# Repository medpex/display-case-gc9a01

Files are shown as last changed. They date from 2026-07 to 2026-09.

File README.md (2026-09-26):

# Display-Case GC9A01 — Tilted Desk Stand

A 15°-tilted desk stand for a round **GC9A01 1.28" TFT** (240×240, SPI) with an
integrated **ESP32-C3 Super Mini**. USB-C reachable from the outside. Print-ready
for Bambu Lab (0.4 mm nozzle, PLA, no supports).

> **Firmware without a toolchain:** flash the display right from your browser —
> **[open the Web Flasher »](https://medpex.github.io/display-case-gc9a01/)**
> (Chrome or Edge, desktop).

**📦 Download the model on [MakerWorld](https://makerworld.com/de/models/3082754-tischstander-fur-gc9a01-1-28-display-esp32-c3).**

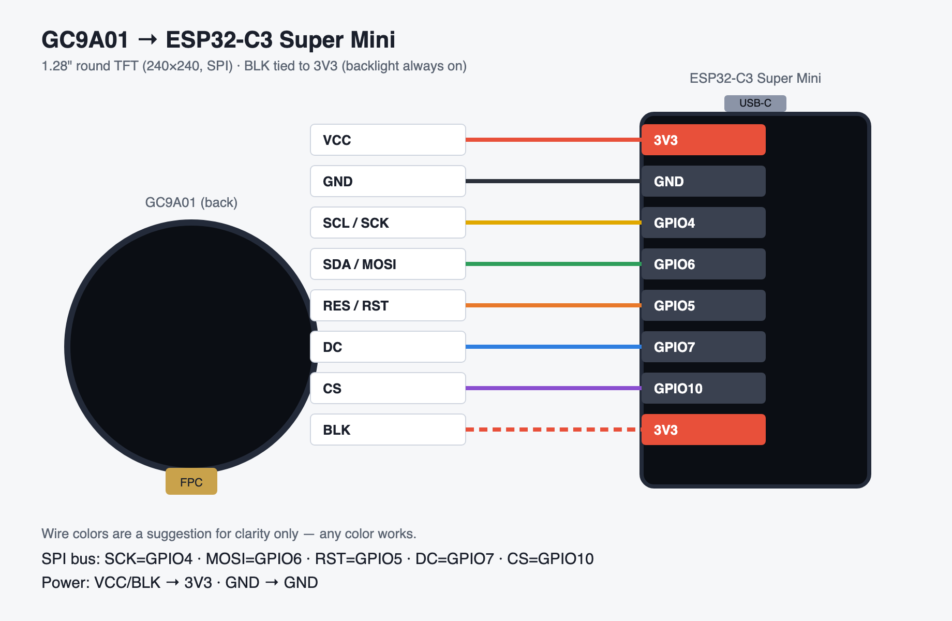
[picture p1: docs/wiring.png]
Wiring diagram


## Housing variants

Both housings use the same electronics, wiring and firmware (web flasher above).

| | Variant | Folder |
|---|---|---|
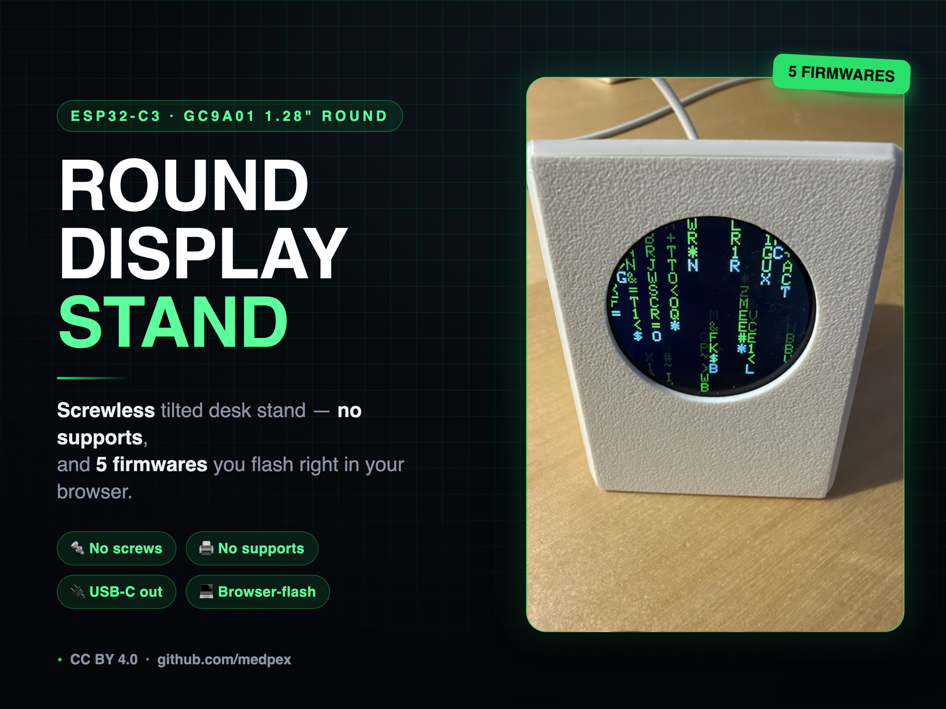
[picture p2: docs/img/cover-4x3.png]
|  | **Wedge stand** (original): 15° wedge, 58 × 52 × 66 mm | this folder (`STL/`, `3MF/`, `STEP/`) |
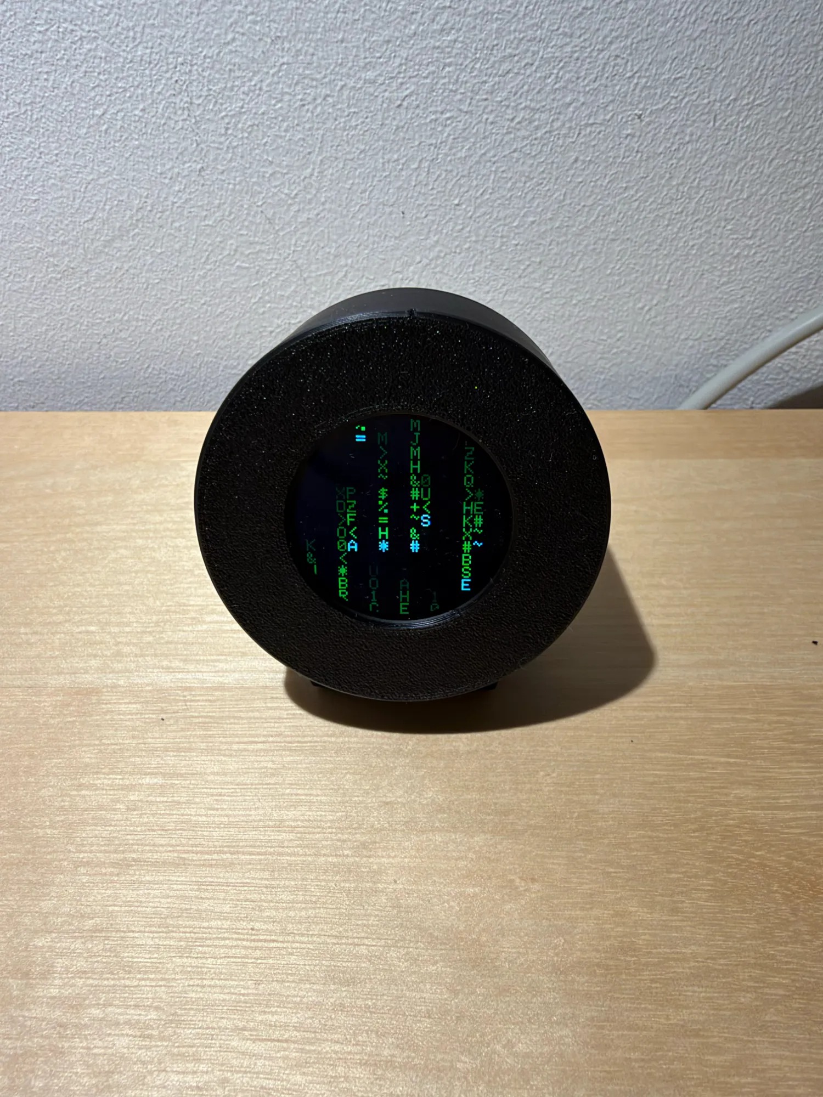
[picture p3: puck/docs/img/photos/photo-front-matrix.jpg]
|  | **Round puck**: ⌀64 mm puck, 15° tilt, wedge foot, lid with ESP32 snap sled | [`puck/`](puck/README.md) |

## Contents

```
Display-Case-GC9A01/
├── STL/                          # print-ready meshes
│   ├── FINAL-Case.stl
│   ├── FINAL-Deckel.stl          # lid (snap-fit)
│   └── FINAL-Klemmring.stl       # clamp ring (holds the display)
├── 3MF/CASE-FINAL-alle-teile.3mf # all parts in one file
├── STEP/CASE-FINAL.step          # parametric CAD (Fusion import)
├── Firmware/
│   ├── esp32_hud/                # GC9A01 HUD (clock/weather/sun/date, WiFi portal)
│   ├── esp32_starfield/          # Warp starfield demo (no WiFi)
│   ├── esp32_matrix/             # Matrix rain demo (no WiFi)
│   ├── esp32_fire/               # demoscene fire demo (no WiFi)
│   └── esp32_plasma/             # full-color plasma demo (no WiFi)
├── puck/                         # round puck variant (own STL/3MF/STEP, Fusion source)
├── docs/                         # GitHub Pages web flasher + wiring diagram
└── BOM.md                        # bill of materials
```

## Wiring (GC9A01 → ESP32-C3 Super Mini)

| Display | ESP32-C3 GPIO |
|---|---|
| VCC | 3V3 |
| GND | GND |
| SCL / SCK | GPIO4 |
| SDA / MOSI | GPIO6 |
| RES / RST | GPIO5 |
| DC | GPIO7 |
| CS | GPIO10 |
| BLK | 3V3 (backlight always on) |

## Firmware

Two sketches are included. Two ways to flash:

### 1. Web flasher (easiest — no software)

Open **<https://medpex.github.io/display-case-gc9a01/>** in Chrome or Edge on a
desktop, plug the ESP32-C3 in via USB-C, and click a flash button. That's it.

- **GC9A01 HUD** — rotating info display: clock, weather, daylight/sun arc and date,
  with a short random animation show once per hour. WiFi and location are set up in
  the browser on first boot (see below). No cloud, no account, no telemetry.
- **Demos** (no WiFi, no setup, run instantly):
  - **Warp Starfield** — flicker-free warp-speed flight through the stars
  - **Matrix Rain** — falling glyph columns with fading trails
  - **Fire** — old-school demoscene fire simulation
  - **Plasma** — full-color plasma waves cycling through the rainbow

#### HUD first-time setup

On first boot the HUD opens a WiFi hotspot **`GC9A01-HUD-Setup`**. Connect a
phone/laptop to it; a captive portal appears where you:

1. select your home WiFi and enter the password;
2. optionally set **City** (display label), **Latitude**, **Longitude** and
   **Timezone** (POSIX, e.g. `CET-1CEST,M3.5.0,M10.5.0/3`) for weather and the clock.

Settings are saved on the device (NVS). Time comes from NTP, weather from
[Open-Meteo](https://open-meteo.com) (no API key). Defaults to Berlin if you skip the
location fields. To change WiFi/location later, flash again — an erase re-opens the portal.

### 2. Self-compile (arduino-cli)

Requires the `esp32:esp32` core ≥ 3.3.7. Important: **`CDCOnBoot=cdc`** (otherwise no
serial / auto-upload on the C3 Super Mini).

```bash
# HUD — libs: "GFX Library for Arduino", ArduinoJson, WiFiManager (tzapu)
arduino-cli compile --upload -p /dev/cu.usbmodemXXXX \
  --fqbn "esp32:esp32:esp32c3:CDCOnBoot=cdc,FlashSize=4M,PartitionScheme=huge_app" \
  Firmware/esp32_hud

# Demos (starfield / matrix / fire / plasma) — libs: "Adafruit GFX Library", "Adafruit GC9A01A"
arduino-cli compile --upload -p /dev/cu.usbmodemXXXX \
  --fqbn "esp32:esp32:esp32c3:CDCOnBoot=cdc,FlashSize=4M" \
  Firmware/esp32_starfield   # or esp32_matrix / esp32_fire / esp32_plasma
```

> Default location can also be changed in `Firmware/esp32_hud/esp32_hud.ino`
> (`DEF_CITY` / `DEF_LAT` / `DEF_LON` / `DEF_TZ`) before compiling.

## Print settings

- **Material:** PLA
- **Layer height:** 0.2 mm
- **Walls:** 1.7 mm (= 4 perimeters at 0.4 mm nozzle)
- **Infill:** ~15 % gyroid
- **Supports:** none (only a short bridge over the USB-C port, prints free)
- **Orientation:** case lying on its back/bottom; lid & clamp ring flat.

## Assembly

1. Drop the display into the boss from the front (D-shape/chin down, FPC through the notch).
2. Put the **clamp ring** on from the back — fixes the display; align its opening to the FPC.
3. Click the ESP32-C3 into the snap holder in the lower area, USB-C toward the port.
4. Wire it up per the table above.
5. Click the **lid** in (snap-fit) — bottom closes flush.
6. Optionally stick 4× rubber feet under the base.

## CAD notes

- Import `STEP/CASE-FINAL.step` into an empty Fusion document to keep editing.
- Internal Fusion length unit = cm; model authored in mm (`c(x)=x*0.1`).
- Key dimensions: wedge 58 D × 52 W × 66 H mm, wall 1.7, floor 2.0, tilt 15°.

## License

- **[Standard Digital File License](LICENSE)** (matches the MakerWorld listing) —
  personal, non-commercial use only. No sharing, remixing, redistribution, hosting
  or commercial use without permission.
- Attribution: *Display-Case GC9A01 by medpex*.
```

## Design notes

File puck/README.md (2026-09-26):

# Display-Puck GC9A01 — Round 15° Desk Puck

A round, 15°-tilted desk puck for a **GC9A01 1.28" round TFT** (240×240, SPI) with an
integrated **ESP32-C3 Super Mini**. It is a variant of
[Display-Case GC9A01](https://makerworld.com/de/models/3082754-tischstander-fur-gc9a01-1-28-display-esp32-c3)
and uses the same electronics, wiring and firmware, in a puck-shaped housing with an
integrated wedge foot. USB-C comes out the back. No screws, no supports.

This folder is part of the [display-case-gc9a01](../README.md) repo. Firmware, web flasher
and wiring diagram live in the repo root.

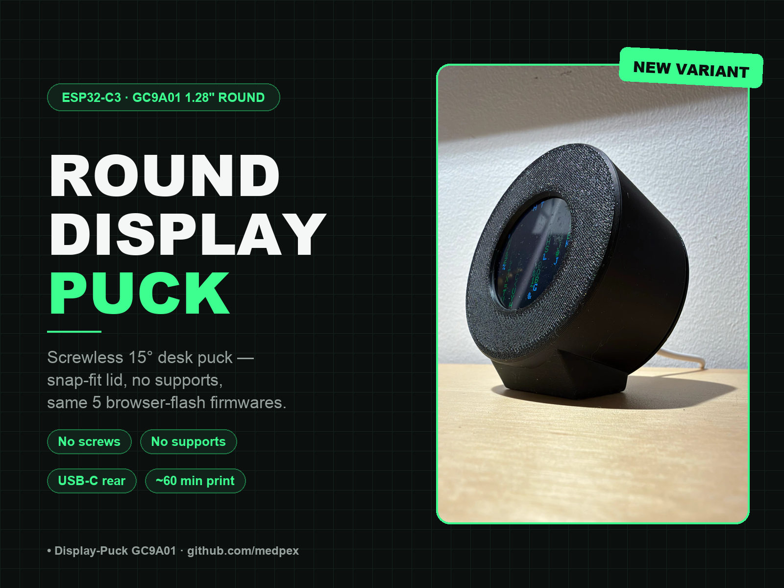
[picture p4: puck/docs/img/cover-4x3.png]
Cover


| Front | Angle | Inside (lid v2 with ESP32 sled) |
|---|---|---|
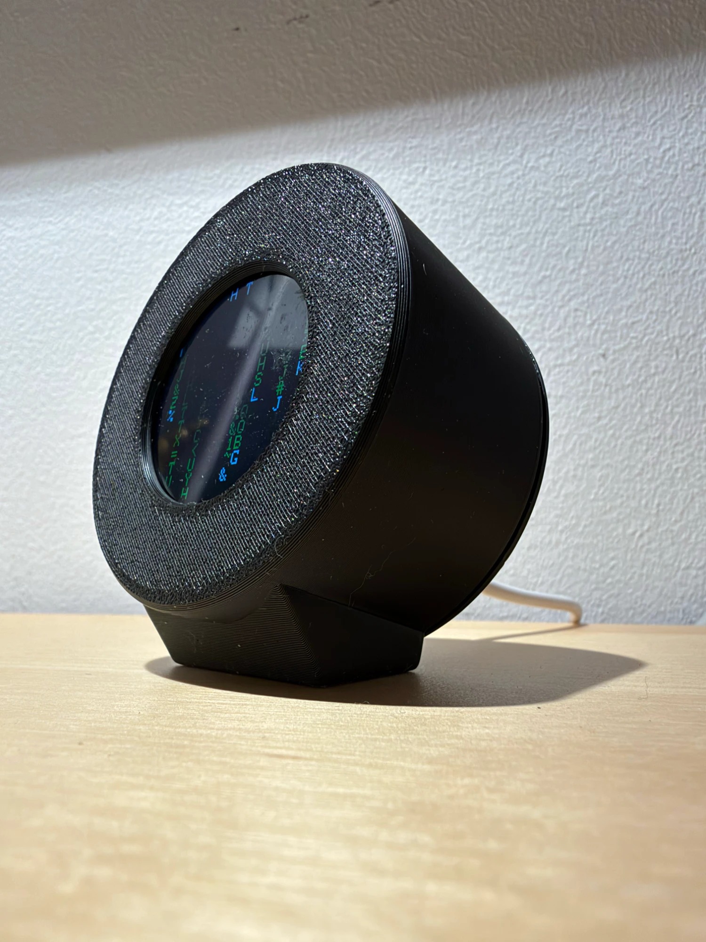
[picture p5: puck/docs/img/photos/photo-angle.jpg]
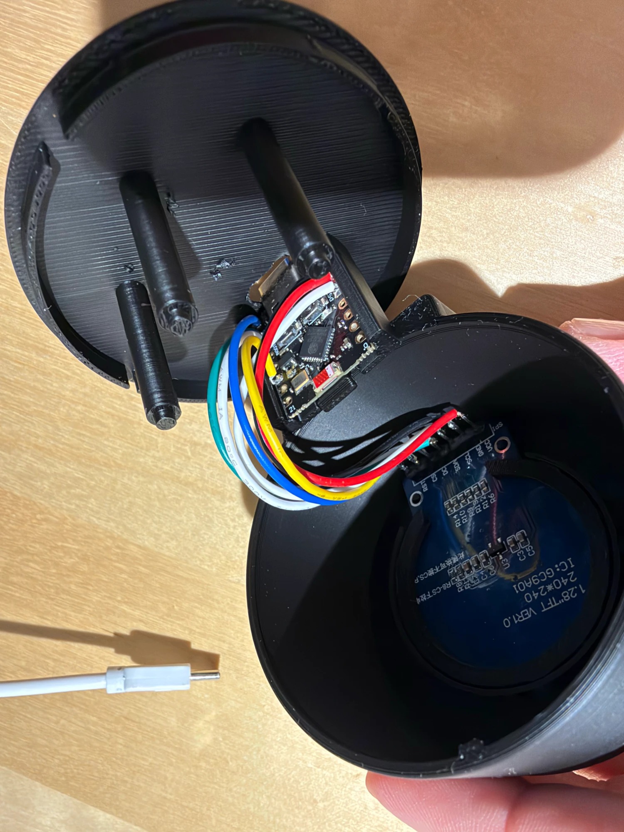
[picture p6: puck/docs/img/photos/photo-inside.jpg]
|  |  |  |

> **Firmware:** same as the original — flash it from your browser with the
> **[Web Flasher](https://medpex.github.io/display-case-gc9a01/)** (Chrome/Edge, desktop).
> The display sits in the same orientation (chin down), so every firmware works unchanged.

| Render | Exploded | Lid v2 with ESP32-C3 |
|---|---|---|
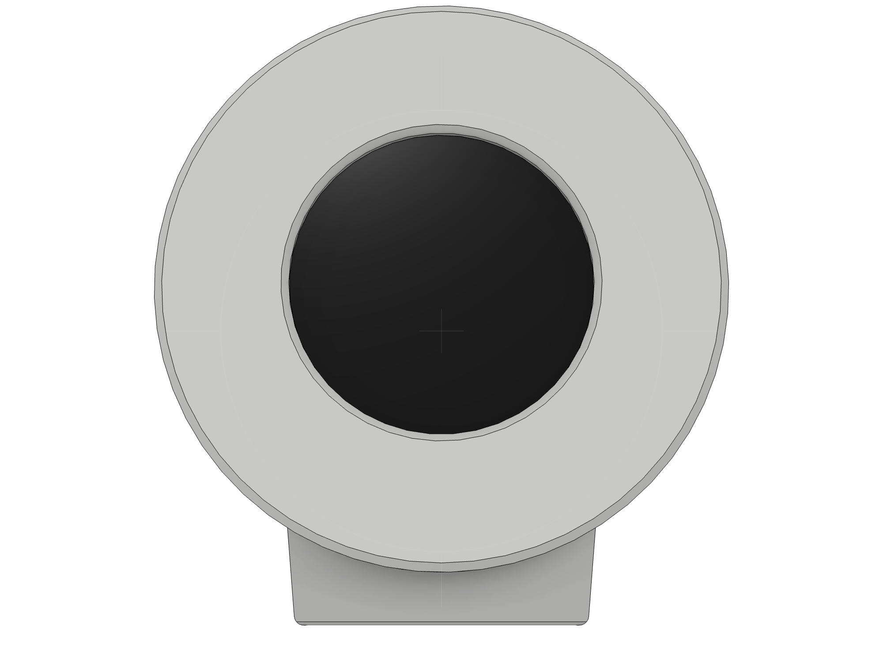
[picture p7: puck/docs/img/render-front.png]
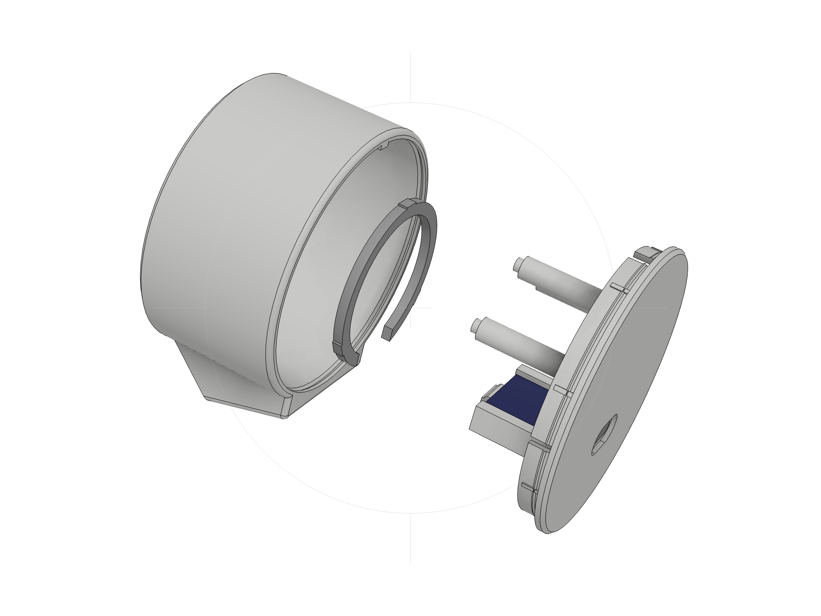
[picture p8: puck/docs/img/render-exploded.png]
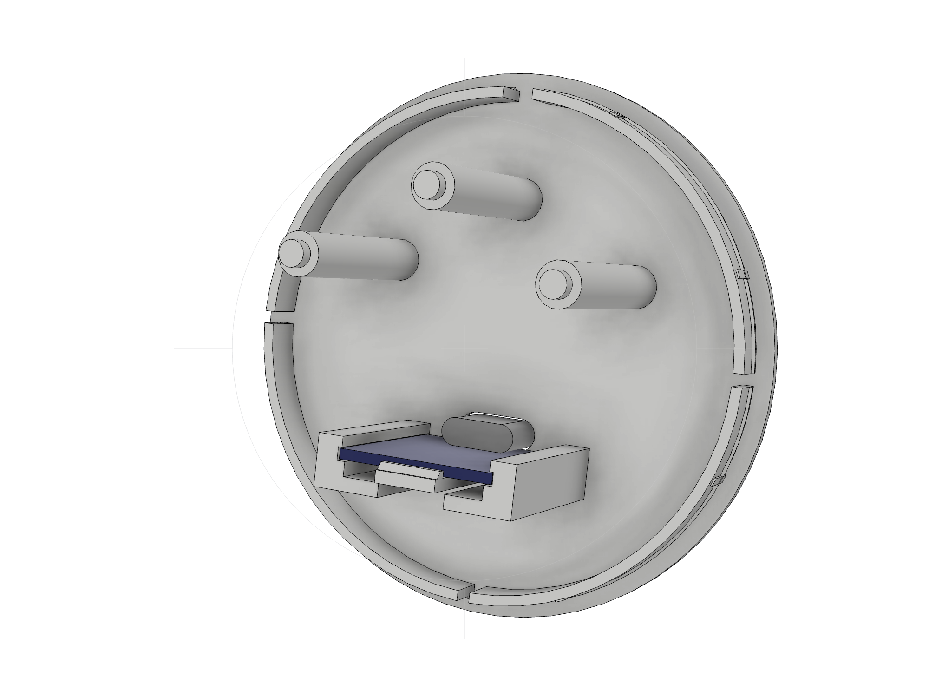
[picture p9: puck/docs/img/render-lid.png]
|  |  |  |

## Key data

| | |
|---|---|
| Size | ⌀64 × 36 mm puck (incl. lid); standing ~72 mm high × ~52 mm deep |
| Tilt | 15° backwards |
| Parts | 3 (housing, lid, clamp ring) |
| Filament | ~36 g PLA (Bambu Studio, A1 0.4, 4 walls, 15 % gyroid) |
| Print time | ~60 min on a Bambu Lab A1 (all 3 parts, one plate); lid alone ~31 min |
| Supports | none |
| Fasteners | none — clamp ring held by 3 posts on the lid, snap-fit lid, snap sled for the ESP32 |

## Contents

```
puck/
├── STL/                          # print-ready meshes, already in print orientation
│   ├── PUCK-Gehaeuse.stl         # housing (front face down)
│   ├── PUCK-Deckel.stl           # lid with ESP32 holder (outer face down)
│   └── PUCK-Klemmring.stl        # clamp ring
├── 3MF/PUCK-alle-teile.3mf       # all parts on one plate (from tools/make_print_files.py)
├── 3MF/PUCK-BambuStudio-A1.3mf   # Bambu Studio project, sliced for A1 (all parts)
├── 3MF/PUCK-Deckel-v2-BambuStudio-A1.3mf # lid v2 only (reprint)
├── 3MF/PUCK-Druckplatte-Fusion.3mf # same plate, exported straight from Fusion
├── STEP/                         # CAD per part + assembly (assembled position)
├── fusion/
│   ├── build_puck.py             # parametric Fusion model (source of truth)
│   ├── Display-Puck-GC9A01.f3d   # Fusion archive
│   ├── layout_print.py           # lay all parts side by side on the plate (+ 3MF export)
│   ├── view_puck.py / render_puck.py / check_interference.py / rebuild.py
├── tools/
│   ├── make_print_files.py       # STL -> print orientation, 3MF, STEP, mesh checks
│   └── make_covers.py            # MakerWorld covers from the Fusion renders
├── docs/img/                     # renders + covers
├── BOM.md                        # bill of materials
└── MAKERWORLD.md                 # listing kit (DE/EN)
```

## Wiring (GC9A01 → ESP32-C3 Super Mini)

Identical to the original case.

| Display | ESP32-C3 GPIO |
|---|---|
| VCC | 3V3 |
| GND | GND |
| SCL / SCK | GPIO4 |
| SDA / MOSI | GPIO6 |
| RES / RST | GPIO5 |
| DC | GPIO7 |
| CS | GPIO10 |
| BLK | 3V3 (backlight always on) |

Wiring diagram

## Print settings

- **Material:** PLA
- **Layer height:** 0.2 mm
- **Walls:** 4 perimeters (0.4 mm nozzle)
- **Infill:** 15 % gyroid
- **Supports:** none. Two short bridges print without support: the USB-C recess (7 mm) and the snap-hook ceilings (1 mm).
- **Orientation:** the STLs are already oriented. Housing front face down, lid outer face down, ring flat.
- **Brim:** not needed (the housing stands on its full ⌀64 front face)

## Assembly

1. **Display:** insert the display through the open back into the round seat, glass
   first, chin/FPC **down** through the opening between the two locating pins.
2. **Clamp ring:** press the ring in from the back with its opening facing down (FPC).
   Its three ribs press-fit into the pocket.
3. **Wiring:** wire the display to the ESP32-C3 using the table above. On the display,
   use a straight header pointing backwards (or solder directly). A right-angle header
   does not fit. On the ESP32, solder directly, or use headers that point towards the
   centre of the puck.
4. **ESP32-C3:** slide the board into the sled on the lid, **USB-C end first**. The
   board rides over the snap tongue underneath until the tongue's nub clicks up behind
   the far end of the board. The USB-C socket now sits in the lid's port. To remove it,
   press the tongue tip down with a small screwdriver and pull the board out.
5. **Lid:** tuck the wires in, line up the lid slot with the key at the top of the
   housing, and press the lid in until the snap bead clicks. The 3 posts on the lid press
   the clamp ring (and the display) forward with 0.3 mm preload.
6. Optional: stick 2 rubber feet (⌀8 mm) under the foot pad.

To open it again, lever the lid out at one of the flex slots with a fingernail or a
plastic spudger.

## Design notes

- **Display mount copied 1:1** from the test-printed original (`CASE-FINAL.step`):
  window ⌀34, glass seat ⌀36 × 1.8, module pocket ⌀39 up to 8 mm, 26 mm chin opening,
  pins ⌀1.5 at (±9.45 / −20.97) for the PCB mounting holes, and the clamp ring
  ⌀38.6/⌀32.8 × 2.2 with 3 press-fit ribs (hull ⌀39.2 in the ⌀39 pocket).
- **Puck ⌀64:** the bore (r 30) clears the module tab corners (r 29.16, tab 23 mm wide,
  7.8 mm below the round PCB) with 0.84 mm to spare.
- **Foot:** the puck's axis is tilted by 15°. Cutting the cylinder flat would eat into the
  inside, so there is a separate wedge foot underneath with a 45° front slope (printable).
  The round cavity stays complete, and the lid rim clears the table by 0.5 mm.
- **Lid (v2):** 5 mm lip slotted in 4 places, 0.1 mm radial clearance plus 8 crush ribs
  (0.1 mm interference; v1 had 0.25 mm and wobbled), and a 45° snap bead that engages a
  groove in the bore, and a key at the top to stop it rotating.
- **ESP32-C3 holder (v2):** rigid U-sled (walls tied together by a floor) plus a flat
  snap tongue under the board centre (0.65 mm travel, ~0.2 % strain). v1 used two
  free-standing 24 mm rails that flexed 0.8 mm across the layer lines; one of them broke
  on the first print. Plugging in a cable pushes the board against the tongue's hook, and
  pulling a cable pushes it against the lid.
- **Display hold-down (v2):** 3 posts on the lid (30°/90°/150°, ⌀5 → ⌀3 tip) press the
  clamp ring against the display PCB (0.3 mm preload, the lid plate flexes). On the
  first print the ring's press fit alone did not hold.
- **Checked:** all parts are closed solids and watertight. A Fusion interference check
  finds no collisions (the only overlap is the intended clamp-ring press fit), ray checks
  through the window and the USB port find no stray material, and the parts slice in
  Bambu Studio without supports.

### Assumptions to verify on the first print

- **ESP32-C3 board 22.6 × 18 × 1.2 mm** (measured; rail slot 1.5 mm). If your board
  rattles, change `PCB_T` / `ESP_L` in `fusion/build_puck.py` and rebuild.
- **Display pin header:** use a **straight** header pointing backwards (Dupont fits) or
  solder the wires directly. A **right-angle header** pointing down (reaches r ≈ 31 mm)
  does **not** fit into the round body.
- **Clamp ring ribs:** if the ring is too tight, sand the ribs lightly. If it is too loose,
  raise `RING_RIB_R` by 0.05.

## Rebuild / edit the CAD

All dimensions are constants at the top of `fusion/build_puck.py`, and the main ones are
also Fusion user parameters.

```bash
# In Fusion: Utilities → Scripts and Add-Ins → + → fusion/build_puck.py → Run
# then regenerate the print files and covers:
python3 tools/make_print_files.py
python3 tools/make_covers.py
```

**Print plate straight from Fusion:** run `fusion/layout_print.py`. It lays the housing
(front face down), the lid (flipped) and the clamp ring side by side on Z=0 (186.6 mm row,
fits the A1/P1S plate) and exports `3MF/PUCK-Druckplatte-Fusion.3mf`. Set
`LAYOUT_MODE = "assembled"` to go back to the assembled view. The housing stays at the
origin, because a Fusion position snapshot resets the first component.

Internal Fusion length unit is cm; the script converts from mm (`cm(x) = x / 10`).

## License

- **[Standard Digital File License](LICENSE)**: personal, non-commercial use only.
- Attribution: *Display-Puck GC9A01 by medpex*, a variant of *Display-Case GC9A01*.

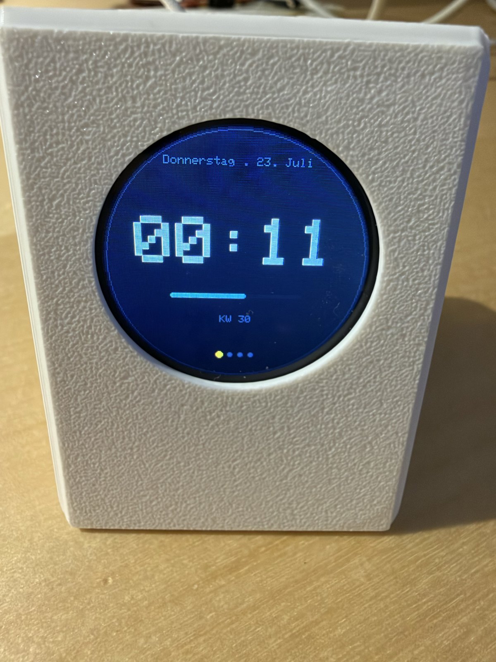
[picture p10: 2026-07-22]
docs/img/gallery-clock.jpg

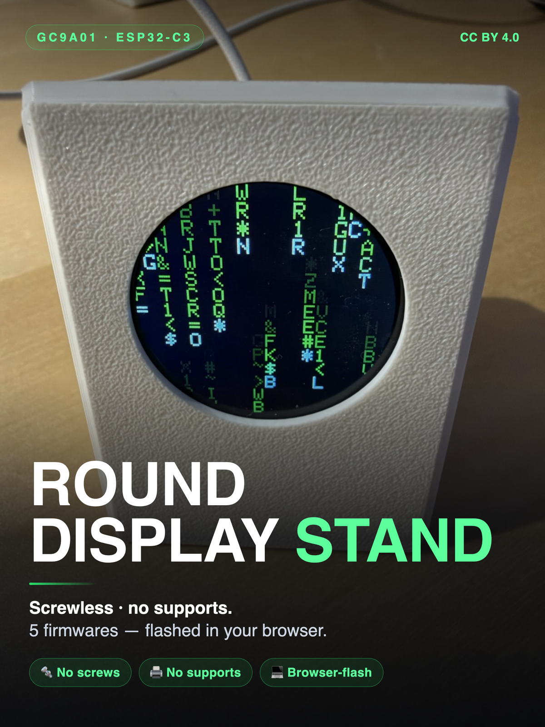
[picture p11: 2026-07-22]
docs/img/cover-3x4.png

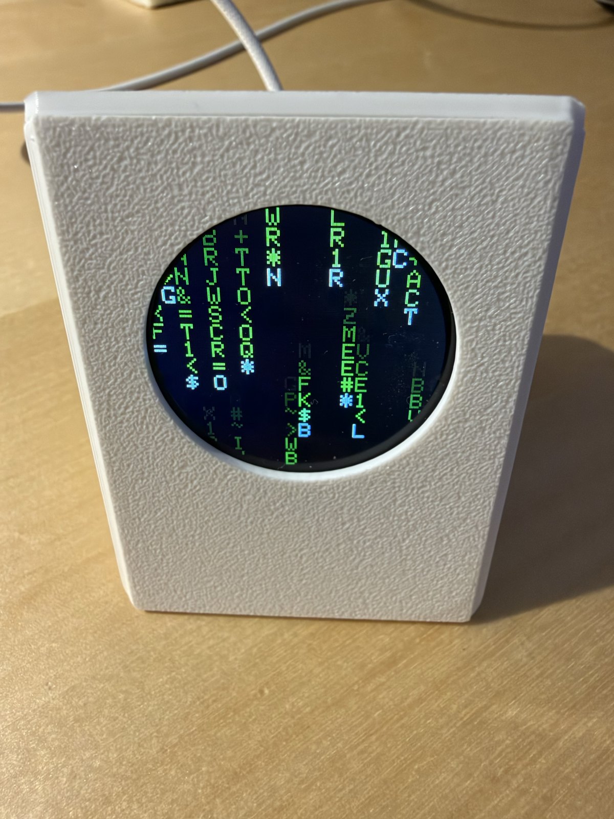
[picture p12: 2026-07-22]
docs/img/gallery-matrix.jpg

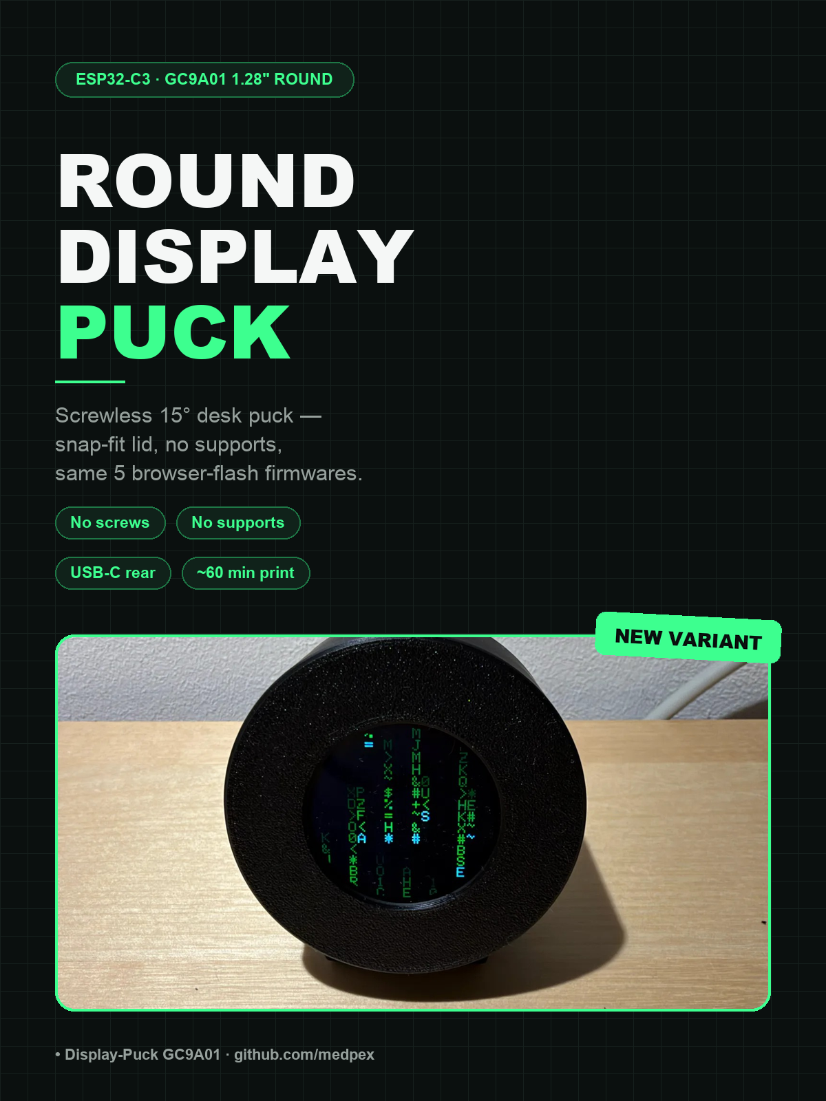
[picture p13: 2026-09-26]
puck/docs/img/cover-3x4.png

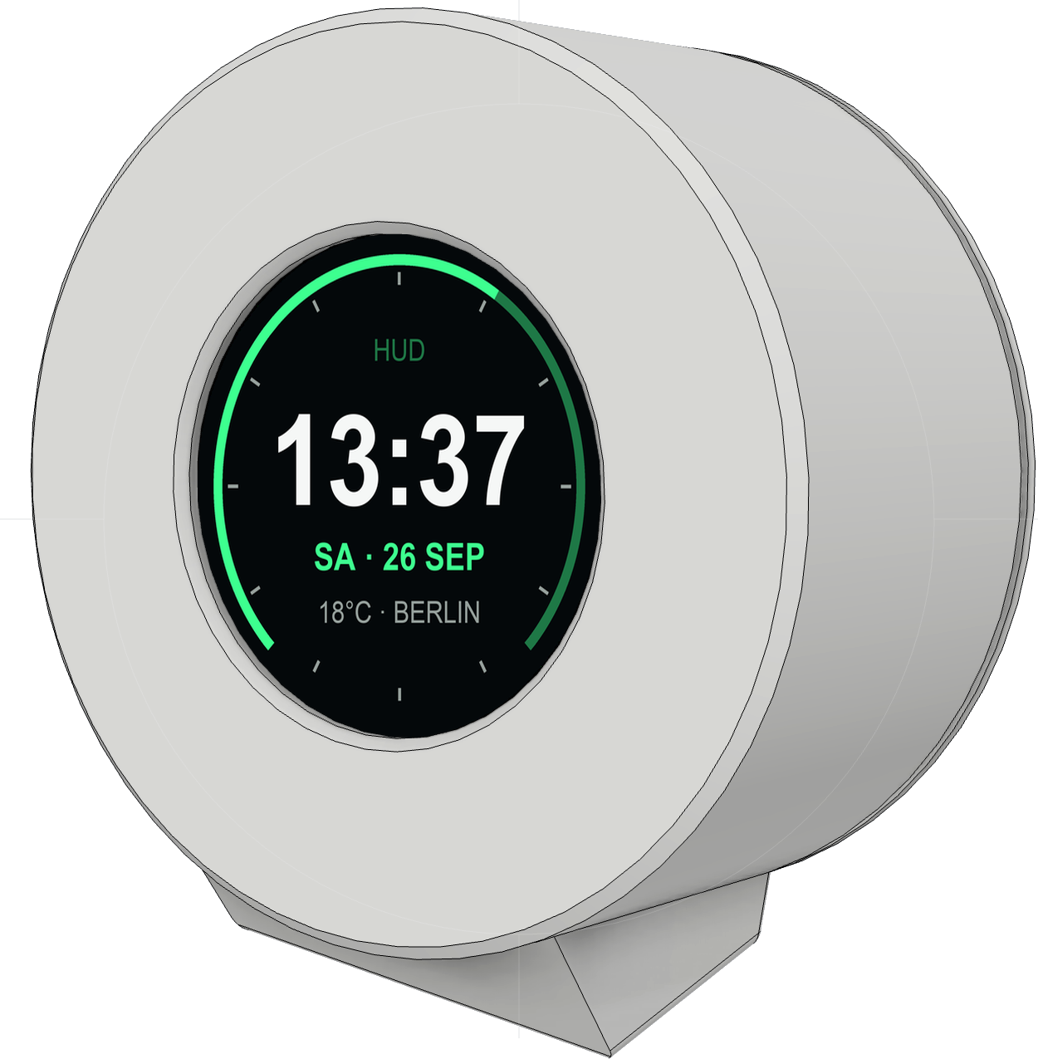
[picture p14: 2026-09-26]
puck/docs/img/hero-screen.png

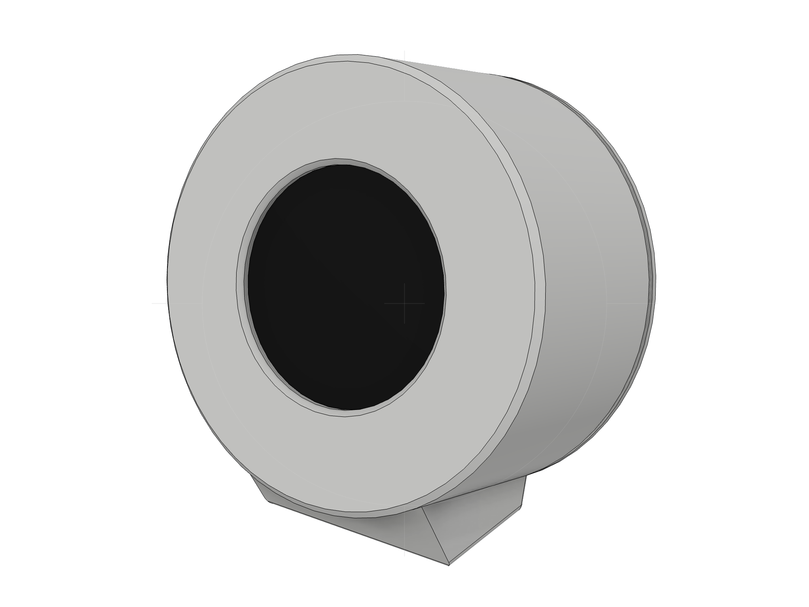
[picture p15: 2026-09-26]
puck/docs/img/render-hero.png

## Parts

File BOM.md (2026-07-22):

# Bestellliste (BOM) — Display-Case GC9A01 Tischständer

Stand: 2026-07-22

## Elektronik / Hardware (zu bestellen)

| # | Teil | Menge | Spezifikation | Suchbegriff / Quelle | ~Preis |
|---|---|---|---|---|---|
| 1 | Rundes TFT-Display | 1× | **GC9A01**, 1.28", 240×240, SPI, 7-Pin (VCC GND SCL SDA RES DC CS, + BLK), Modul ⌀38 mm | "1.28 inch round TFT GC9A01" (AliExpress/Amazon), Datenblatt **MSP1281** | 5–8 € |
| 2 | Mikrocontroller | 1× | **ESP32-C3 Super Mini**, WiFi+BLE, USB-C, 22.5×18 mm | "ESP32-C3 Super Mini" | 3–5 € |
| 3 | Jumper-Kabel | 7 (–8) | Dupont/Silikon female-female, ~10 cm | "Dupont Kabel F-F Set" | 2 € |
| 4 | USB-C Datenkabel | 1× | Daten + Strom (kein reines Ladekabel) | vorhanden / — | 0–3 € |
| 5 | Filament | ~30 g | PLA (beliebige Farbe), 1.75 mm | Bambu Lab / beliebig | ~1 € |
| 6 | Anti-Rutsch-Füße | 4× | selbstklebend, ⌀8–9 mm (optional, für Standfestigkeit) | "Gummifüße selbstklebend 8mm" | 2 € |

**Keine Schrauben nötig** — Deckel per Snap-Fit, Display per Klemmring + Stiften fixiert.

## Gedruckte Teile (in diesem Projekt, STL/-Ordner)

| Teil | Datei | Material | Notiz |
|---|---|---|---|
| Gehäuse | `STL/FINAL-Case.stl` | PLA | Hauptkörper mit Display-Boss, ESP-Halter, USB-C-Port |
| Deckel | `STL/FINAL-Deckel.stl` | PLA | einklickbar (Snap-Fit), Boden |
| Klemmring | `STL/FINAL-Klemmring.stl` | PLA | fixiert Display von hinten |

Gesamt-Materialverbrauch ~25–30 g PLA.

## Gesamtkosten (Elektronik)

ca. **12–20 €** je nach Bezugsquelle (Kabel/USB oft schon vorhanden).

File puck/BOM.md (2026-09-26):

# Bestellliste (BOM) — Display-Puck GC9A01

Stand: 2026-09-26. Elektronik identisch zum Original *Display-Case GC9A01*.

## Elektronik / Hardware

| # | Teil | Menge | Spezifikation | Suchbegriff | ~Preis |
|---|---|---|---|---|---|
| 1 | Rundes TFT-Display | 1× | **GC9A01**, 1.28", 240×240, SPI, 7-Pin + BLK, Modul ⌀38 mm, **gerade Stiftleiste nach hinten** (Winkel-Header passt nicht) | "1.28 inch round TFT GC9A01" | 5–8 € |
| 2 | Mikrocontroller | 1× | **ESP32-C3 Super Mini**, USB-C, 22,6 × 18 × 1,2 mm | "ESP32-C3 Super Mini" | 3–5 € |
| 3 | Litze / Jumper-Kabel | 7–8 | Silikonlitze oder Dupont F-F, ~8–10 cm | "Dupont Kabel F-F" | 2 € |
| 4 | USB-C Datenkabel | 1× | Daten + Strom | vorhanden | 0–3 € |
| 5 | Filament | ~36 g | PLA, 1,75 mm | beliebig | ~1 € |
| 6 | Gummifüße (optional) | 2× | selbstklebend ⌀8 mm | "Gummifüße 8mm" | 1 € |

**Keine Schrauben.** Klemmring wird von 3 Stempeln am Deckel gehalten, Deckel per Rastwulst + Quetschrippen, ESP32 per Schnapp-Schlitten.

## Gedruckte Teile

| Teil | Datei | Druckorientierung |
|---|---|---|
| Gehäuse | `STL/PUCK-Gehaeuse.stl` | Front nach unten |
| Deckel mit ESP32-Halter | `STL/PUCK-Deckel.stl` | Außenseite nach unten |
| Klemmring | `STL/PUCK-Klemmring.stl` | flach |

Alle drei zusammen: `3MF/PUCK-alle-teile.3mf`. Bambu A1 0.4: ~60 min, ~36 g PLA, ohne Support. Nur Deckel v2: `3MF/PUCK-Deckel-v2-BambuStudio-A1.3mf` (~31 min, ~12 g).

## Gesamtkosten Elektronik

ca. **12–20 €**

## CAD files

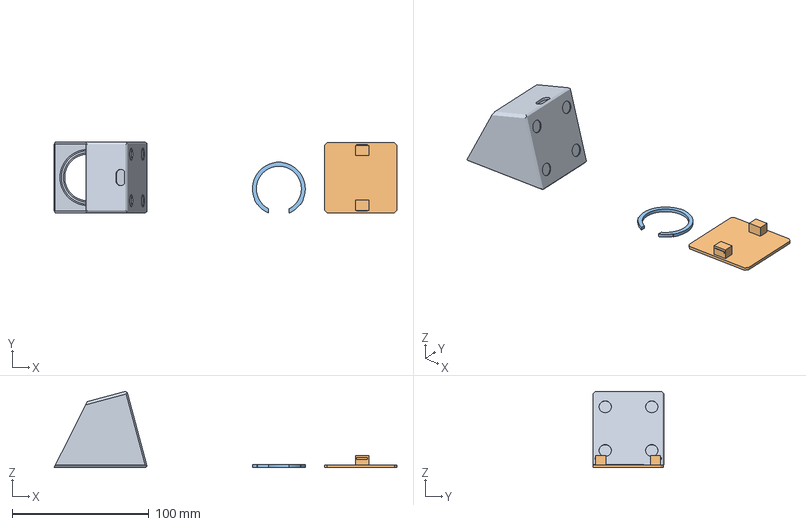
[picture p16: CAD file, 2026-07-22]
3MF/CASE-FINAL-alle-teile.3mf
250.6 x 52.0 x 55.7 mm
Case
Deckel
Klemmring

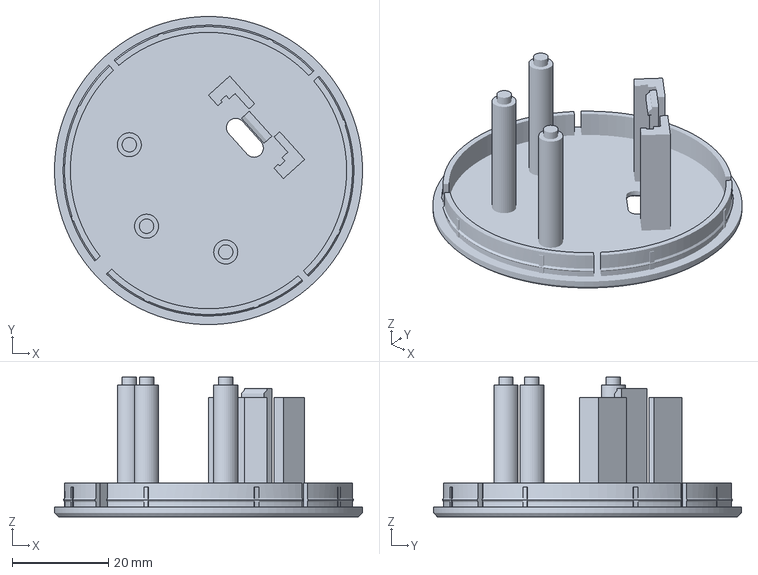
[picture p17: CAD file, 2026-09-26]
puck/3MF/PUCK-Deckel-v2-BambuStudio-A1.3mf
64.0 x 64.0 x 29.0 mm

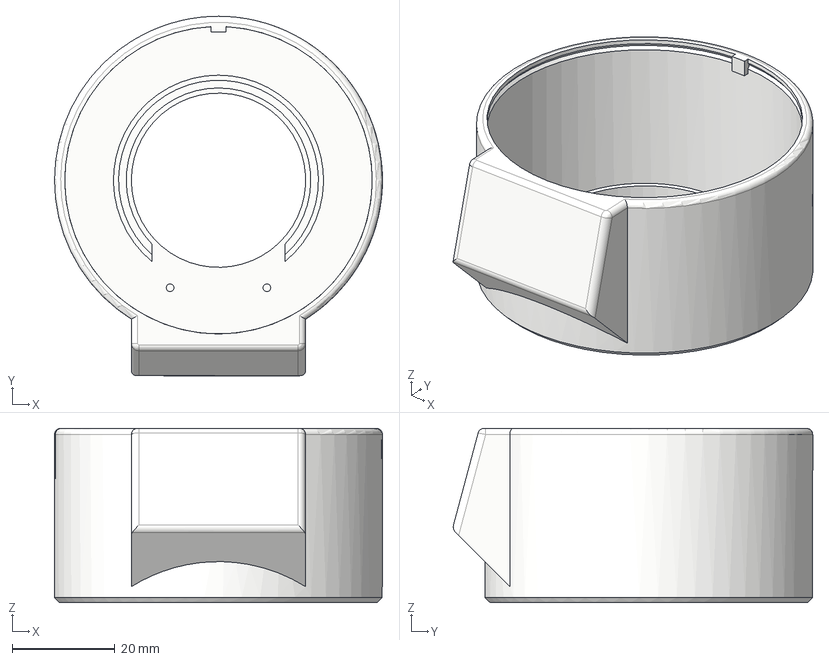
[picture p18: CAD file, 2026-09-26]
puck/STEP/PUCK-Gehaeuse.step
64.0 x 70.2 x 34.0 mm

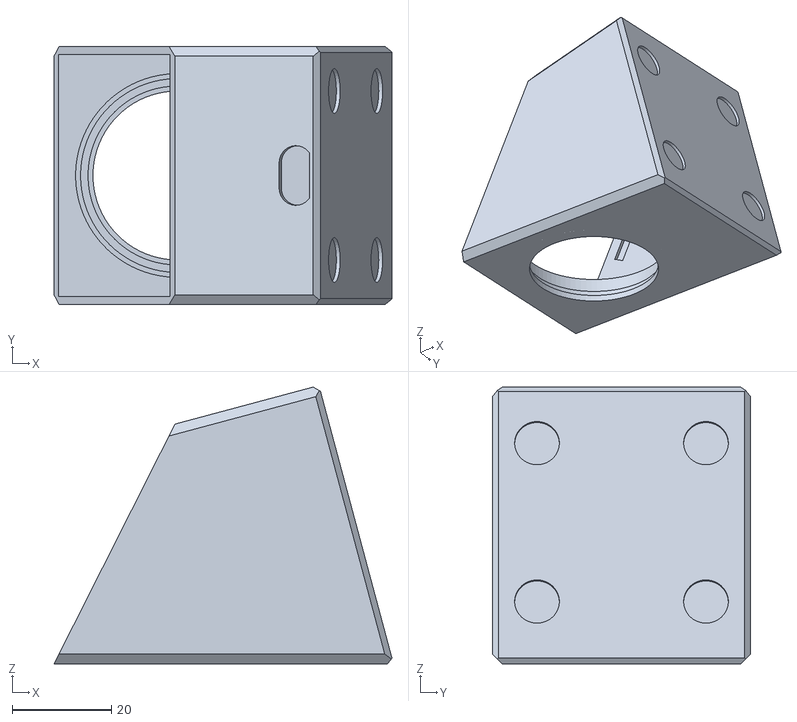
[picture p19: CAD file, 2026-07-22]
STL/FINAL-Case.stl
68.0 x 52.0 x 55.7

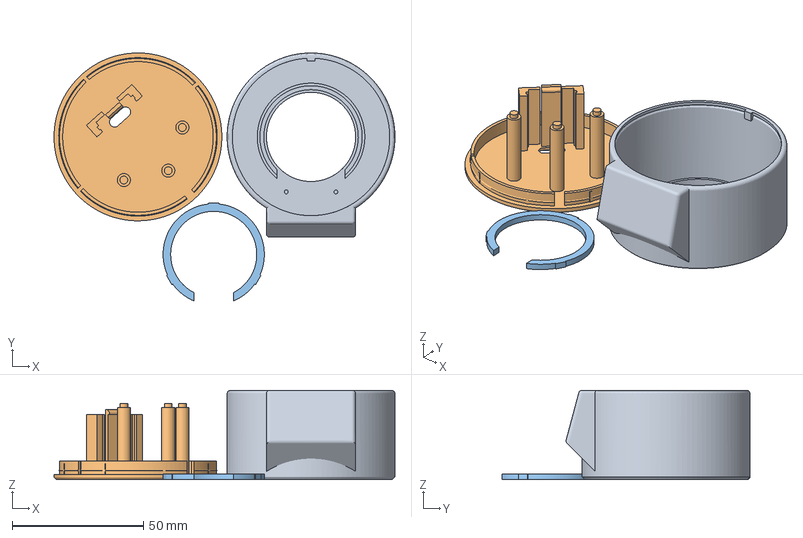
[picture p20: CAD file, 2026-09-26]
puck/3MF/PUCK-BambuStudio-A1.3mf
130.0 x 94.6 x 34.0 mm
PUCK-Gehaeuse.stl
PUCK-Deckel.stl
PUCK-Klemmring.stl

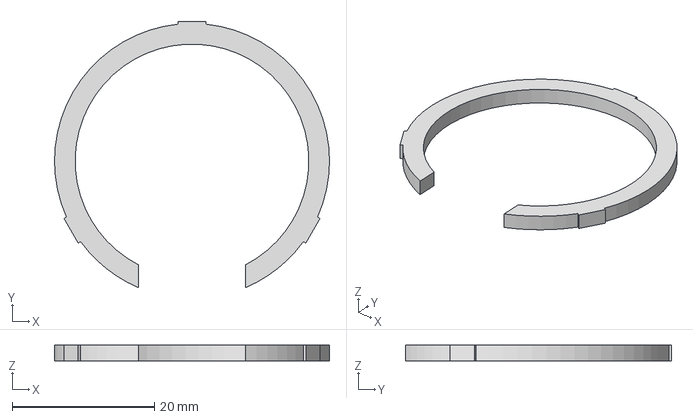
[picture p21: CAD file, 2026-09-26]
puck/STEP/PUCK-Klemmring.step
38.6 x 37.4 x 2.20 mm

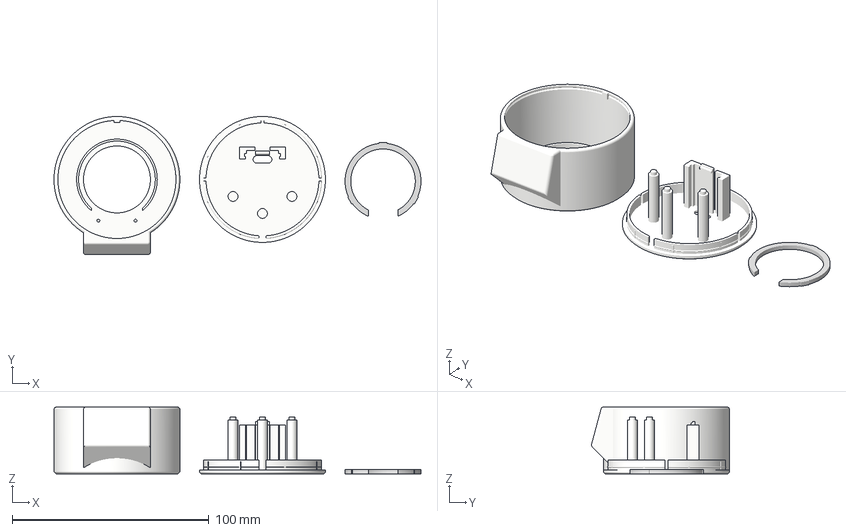
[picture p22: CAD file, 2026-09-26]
puck/3MF/PUCK-Druckplatte-Fusion.3mf
186.6 x 70.2 x 34.0 mm
Deckel
Gehaeuse
Klemmring

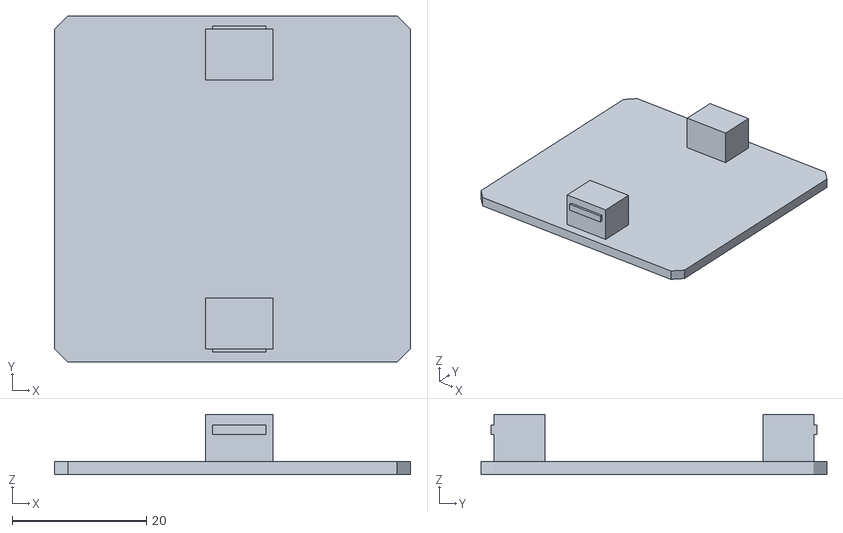
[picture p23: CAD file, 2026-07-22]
STL/FINAL-Deckel.stl
53.0 x 51.5 x 9.00

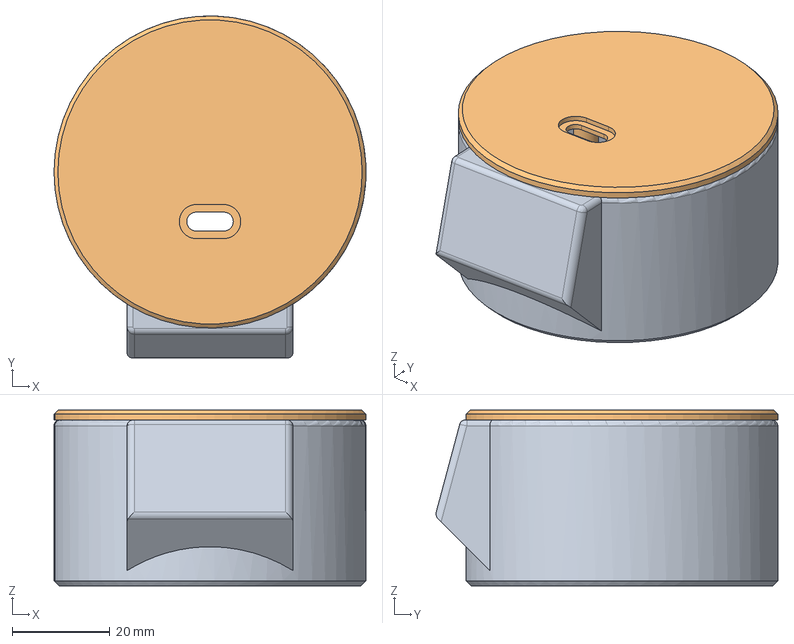
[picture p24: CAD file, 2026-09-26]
puck/STEP/PUCK-alle-teile.step
64.0 x 70.1 x 36.0 mm
Gehaeuse
Deckel
Klemmring

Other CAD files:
STEP/CASE-FINAL.step
STL/FINAL-Klemmring.stl
puck/STEP/PUCK-Deckel.step
puck/3MF/PUCK-alle-teile.3mf
puck/STL/PUCK-Deckel.stl
puck/STL/PUCK-Gehaeuse.stl
puck/STL/PUCK-Klemmring.stl
puck/fusion/Display-Puck-GC9A01.f3d

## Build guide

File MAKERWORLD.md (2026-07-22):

# MakerWorld — Listing-Kit (zum Reinkopieren)

Alles fertig zum Einfügen in das MakerWorld-Upload-Formular. Reihenfolge folgt den
Formularfeldern. Zweisprachig (DE zuerst, EN darunter für internationale Reichweite —
MakerWorld-Publikum ist global; EN bringt deutlich mehr Downloads/Boosts).

Bild `docs/wiring.png` als Galerie-/Instruction-Bild hochladen. Cover-Foto vom
gedruckten Teil noch aufnehmen (siehe **Bild-Checkliste** unten).

---

## 1) TITEL (Design Name)

**Empfehlung (DE):**
> Runder Tischständer für GC9A01 1.28" Display + ESP32-C3 (Web-Flasher, schraubenlos)

**Empfehlung (EN):**
> Round Desk Stand for GC9A01 1.28" Display + ESP32-C3 — Browser-Flash, Screwless

**Alternativen (Titel darf kurz & suchstark sein):**
- GC9A01 1.28" Round Display Case & Desk Stand (ESP32-C3, no screws)
- Info-Display Ständer — GC9A01 + ESP32-C3, 5 Firmwares im Browser flashen
- Round TFT Desk Clock/HUD — GC9A01 + ESP32-C3, snap-fit, web flasher

---

## 2) SUMMARY / KURZBESCHREIBUNG (1 Zeile)

**DE:** 15° gekippter, schraubenloser Tischständer für ein rundes GC9A01 1.28"-TFT mit ESP32-C3 — inkl. 5 fertigen Firmwares, die man ohne Software direkt im Browser flasht.

**EN:** 15°-tilted, screwless desk stand for a round GC9A01 1.28" TFT with ESP32-C3 — includes 5 ready-made firmwares you flash straight from your browser, no software.

---

## 3) KATEGORIE & TAGS

- **Kategorie:** Gadgets / Electronics (bzw. „Hobby & DIY → Electronics")
- **Tags:** `ESP32`, `ESP32-C3`, `GC9A01`, `Round Display`, `TFT`, `Desk Stand`, `Clock`, `Weather Station`, `Snap-fit`, `No Supports`, `USB-C`, `Arduino`

---

## 4) BESCHREIBUNG (Description) — DEUTSCH

### Runder Info-Display-Ständer für GC9A01 + ESP32-C3

Gekippter (15°) Tischständer für ein rundes **GC9A01 1.28"-TFT** (240×240, SPI) mit
integriertem **ESP32-C3 Super Mini**. USB-C bleibt von außen erreichbar — Flashen und
Strom ohne Öffnen. Komplett **schraubenlos**: Display per Klemmring fixiert, Deckel per
Snap-Fit. Druckt **ohne Support** (nur eine kurze, frei druckende Brücke über dem USB-C-Port).

**Getestet:** Display-Aufnahme, Klemmring, Deckel-Snap und USB-C-Port per Testdruck bestätigt.

#### ✨ Highlights
- 🔩 **Keine Schrauben** — Display per Klemmring, Deckel per Snap-Fit
- 🖨️ **Kein Support** nötig
- 🔌 **USB-C von außen** zugänglich
- 🧩 3 Teile, ~25–30 g PLA gesamt
- 💻 **5 fertige Firmwares**, die du **ohne Arduino/Toolchain direkt im Browser flashst**

#### 💻 Firmware im Browser flashen — keine Software nötig
Über den **Web-Flasher** (Chrome/Edge am Desktop) flashst du per Klick:
- **GC9A01 HUD** — rotierendes Info-Display: Uhr · Wetter · Sonnenstand/Tageslicht · Datum,
  dazu einmal pro Stunde eine kleine Animations-Show. WLAN & Ort werden beim ersten Start
  bequem im Browser eingerichtet (Captive-Portal).
- **4 Demos ohne Setup:** Warp Starfield · Matrix Rain · Fire · Plasma

**👉 Web-Flasher:** https://medpex.github.io/display-case-gc9a01/

**HUD-Ersteinrichtung:** Beim 1. Start spannt das Display den WLAN-Hotspot
`GC9A01-HUD-Setup` auf → damit verbinden → WLAN wählen und optional Ort (Stadt/Breite/Länge)
+ Zeitzone setzen. Danach: Zeit per NTP, Wetter per Open-Meteo — **kein API-Key, kein
Account, keine Cloud, keine Telemetrie.** Ohne Ortsangabe: Default Berlin.

#### 🔧 Verkabelung (GC9A01 → ESP32-C3 Super Mini)
| Display | ESP32-C3 |
|---|---|
| VCC | 3V3 |
| GND | GND |
| SCL / SCK | GPIO4 |
| SDA / MOSI | GPIO6 |
| RES / RST | GPIO5 |
| DC | GPIO7 |
| CS | GPIO10 |
| BLK | 3V3 (Backlight dauerhaft an) |

→ Verkabelungs-Diagramm siehe Galerie.

#### 🧰 Benötigte Elektronik (nicht enthalten)
- 1× GC9A01 1.28" Rund-TFT, 240×240, SPI (7-Pin + BLK)
- 1× ESP32-C3 Super Mini (USB-C)
- 7× Dupont-Kabel female/female
- optional: 4× selbstklebende Gummifüße

#### 🛠️ Montage
1. Display von vorn in die Aufnahme legen (D-Form/Kinn nach unten, FPC durch die Ausbuchtung).
2. Klemmring von hinten aufsetzen (Öffnung zum FPC ausrichten) — fixiert das Display.
3. ESP32-C3 auf den Boden setzen, USB-C zum Port.
4. Laut Tabelle verkabeln.
5. Deckel einklicken (Snap-Fit).
6. Optional 4× Gummifüße unter den Boden.

#### 📄 Lizenz
**Standard-Digitaldateilizenz** — nur persönliche, nicht-kommerzielle Nutzung.
Kein Teilen, Remixen, Weiterverbreiten oder kommerzielle Nutzung ohne Genehmigung.
Quellcode, Firmware & Doku: https://github.com/medpex/display-case-gc9a01

---

## 5) DESCRIPTION — ENGLISH

### Round Info-Display Desk Stand for GC9A01 + ESP32-C3

A 15°-tilted desk stand for a round **GC9A01 1.28" TFT** (240×240, SPI) with an integrated
**ESP32-C3 Super Mini**. USB-C stays reachable from the outside — flash and power without
opening it. Completely **screwless**: the display is held by a clamp ring, the lid snaps in.
Prints **without supports** (only a short self-bridging span over the USB-C port).

**Tested:** display mount, clamp ring, lid snap and USB-C port all confirmed by a test print.

#### ✨ Highlights
- 🔩 **No screws** — clamp ring for the display, snap-fit lid
- 🖨️ **No supports** needed
- 🔌 **USB-C accessible** from outside
- 🧩 3 parts, ~25–30 g PLA total
- 💻 **5 ready-made firmwares** you flash **straight from your browser** — no Arduino, no toolchain

#### 💻 Flash firmware in your browser — no software
Using the **web flasher** (Chrome/Edge on desktop), flash with one click:
- **GC9A01 HUD** — rotating info display: clock · weather · daylight/sun arc · date, plus a
  short animation show once an hour. WiFi & location are set up in the browser on first boot.
- **4 zero-setup demos:** Warp Starfield · Matrix Rain · Fire · Plasma

**👉 Web flasher:** https://medpex.github.io/display-case-gc9a01/

**HUD first-time setup:** on first boot it opens a WiFi hotspot `GC9A01-HUD-Setup` → connect →
pick your WiFi and optionally set City/Latitude/Longitude + Timezone. Time via NTP, weather via
Open-Meteo — **no API key, no account, no cloud, no telemetry.** Defaults to Berlin.

#### 🔧 Wiring (GC9A01 → ESP32-C3 Super Mini)
| Display | ESP32-C3 |
|---|---|
| VCC | 3V3 |
| GND | GND |
| SCL / SCK | GPIO4 |
| SDA / MOSI | GPIO6 |
| RES / RST | GPIO5 |
| DC | GPIO7 |
| CS | GPIO10 |
| BLK | 3V3 (backlight always on) |

→ See the wiring diagram in the gallery.

#### 🧰 Required electronics (not included)
- 1× GC9A01 1.28" round TFT, 240×240, SPI (7-pin + BLK)
- 1× ESP32-C3 Super Mini (USB-C)
- 7× Dupont female/female jumper wires
- optional: 4× self-adhesive rubber feet

#### 🛠️ Assembly
1. Drop the display into the mount from the front (D-shape/chin down, FPC through the notch).
2. Put the clamp ring on from the back (opening aligned to the FPC) — it fixes the display.
3. Place the ESP32-C3 on the floor, USB-C toward the port.
4. Wire it up per the table.
5. Snap the lid in.
6. Optionally add 4 rubber feet.

#### 📄 License
**Standard Digital File License** — personal, non-commercial use only. No sharing,
remixing, redistribution or commercial use without permission.
Source, firmware & docs: https://github.com/medpex/display-case-gc9a01

---

## 6) DRUCKPROFIL / PRINT SETTINGS (MakerWorld „Print Profile"-Felder)

| Setting | Value |
|---|---|
| Material | PLA |
| Nozzle | 0.4 mm |
| Layer height | 0.2 mm |
| Walls / Perimeters | 1.7 mm (4 @ 0.4 mm) |
| Infill | ~15 % Gyroid |
| Supports | **None** |
| Plate orientation | Case on its back/bottom; lid & clamp ring flat |
| Filament used | ~25–30 g total |
| Est. print time | ~2–3 h (drucker-/profilabhängig) |

**Teile (3):** `FINAL-Case.stl`, `FINAL-Deckel.stl`, `FINAL-Klemmring.stl`
(bzw. `CASE-FINAL-alle-teile.3mf` = alle in einer Platte).

> ⚠️ Vor Upload STL/3MF neu exportieren — Deckel-Snap wurde zuletzt gefixt
> (Widerhaken 0,5 mm nach außen). Alte Dateien haben den Fix noch nicht.

---

## 7) BILD-CHECKLISTE (Cover + Galerie)

MakerWorld belohnt gute Fotos. Reihenfolge = Cover zuerst.
- [x] **Web-/App-Cover 4:3:** `docs/img/cover-4x3.png` (1600×1200, fertig)
- [x] **App-Cover 3:4:** `docs/img/cover-3x4.png` (1200×1600, fertig)
- [x] Galerie: `gallery-matrix.jpg`, `gallery-clock.jpg`, `gallery-weather.jpg`, `gallery-sun.jpg`, `gallery-wifi-setup.jpg`, `gallery-matrix-angle.jpg` (alle in `docs/img/`)
- [x] **`docs/wiring.png`** (Verkabelungs-Diagramm)
- [ ] noch schön: 3 Teile zerlegt nebeneinander (Case / Deckel / Klemmring)
- [ ] noch schön: Rückseite mit sichtbarem USB-C-Port
- [ ] optional: Screenshot der Web-Flasher-Seite (zeigt „flash im Browser")

---

## 8) LINKS

- **Web-Flasher:** https://medpex.github.io/display-case-gc9a01/
- **GitHub (Source/Firmware/Doku):** https://github.com/medpex/display-case-gc9a01

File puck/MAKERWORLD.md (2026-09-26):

# MakerWorld — Listing-Kit „Display-Puck GC9A01“ (zum Reinkopieren)

Neues Modell, zweisprachig wie das Original. Upload am besten als **eigenes Modell** mit Verweis
auf das Original. Alternativ geht es als zweites Druckprofil beim Original, dann wirkt der Cover aber
weniger. In beiden Beschreibungen gegenseitig verlinken.

Bilder: `docs/img/cover-4x3.png`, `docs/img/cover-3x4.png`, Galerie siehe **Bild-Checkliste**.

---

## 1) TITEL

**DE:** Runder Display-Puck für GC9A01 1.28" + ESP32-C3 (15° gekippt, schraubenlos, Web-Flasher)

**EN:** Round Display Puck for GC9A01 1.28" + ESP32-C3 — 15° Tilt, Screwless, Browser-Flash

Alternativen:
- GC9A01 Round Desk Puck — ESP32-C3, snap-fit, no supports
- Round TFT Puck Clock/HUD — GC9A01 + ESP32-C3, 49 min print

---

## 2) SUMMARY

**DE:** Runder 15°-Puck mit angeformtem Keilfuß für das GC9A01 1.28"-TFT + ESP32-C3. Schraubenlos, ohne Support, ~49 min Druck. Dieselben 5 Browser-Firmwares wie der Original-Ständer.

**EN:** Round 15° puck with an integrated wedge foot for the GC9A01 1.28" TFT + ESP32-C3 — screwless, no supports, ~49 min print, same 5 browser-flash firmwares as the original stand.

---

## 3) KATEGORIE & TAGS

- **Kategorie:** Gadgets / Electronics
- **Tags:** `ESP32`, `ESP32-C3`, `GC9A01`, `Round Display`, `TFT`, `Desk Clock`, `Puck`, `Weather Station`, `Snap-fit`, `No Supports`, `USB-C`, `Arduino`

---

## 4) BESCHREIBUNG — DEUTSCH

### Runder Display-Puck für GC9A01 + ESP32-C3

Neue Variante meines [Tischständers für das GC9A01](https://makerworld.com/de/models/3082754-tischstander-fur-gc9a01-1-28-display-esp32-c3).
Diesmal als **runder Puck (⌀64 mm)**, 15° nach hinten gekippt, auf einem angeformten Keilfuß.
Elektronik, Verkabelung und Firmware sind identisch zum Original. Die Display-Aufnahme ist
1:1 aus dem getesteten Original übernommen.

#### ✨ Highlights
- ⭕ **Runde Form**: das runde Display sitzt mittig im runden Gehäuse
- 🔩 **Keine Schrauben**: Klemmring mit Pressrippen, Deckel per Rastwulst, ESP32 per Schnapp-Schienen am Deckel
- 🖨️ **Kein Support**: ~49 min Druck auf einem Bambu A1, ~33 g PLA, alle 3 Teile auf einer Platte
- 🔌 **USB-C hinten** mit Senkung für den Stecker
- 💻 **5 fertige Firmwares** zum Flashen direkt im Browser, ohne Arduino

#### 💻 Firmware im Browser flashen
Mit dem **Web-Flasher** (Chrome/Edge am Desktop) per Klick:
- **GC9A01 HUD**: Uhr · Wetter · Sonnenstand · Datum. WLAN und Ort richtest du beim ersten Start im Browser ein.
- **4 Demos ohne Setup:** Warp Starfield · Matrix Rain · Fire · Plasma

**👉 Web-Flasher:** https://medpex.github.io/display-case-gc9a01/

#### 🔧 Verkabelung (GC9A01 → ESP32-C3 Super Mini)
| Display | ESP32-C3 |
|---|---|
| VCC | 3V3 |
| GND | GND |
| SCL / SCK | GPIO4 |
| SDA / MOSI | GPIO6 |
| RES / RST | GPIO5 |
| DC | GPIO7 |
| CS | GPIO10 |
| BLK | 3V3 |

#### 🧰 Benötigte Elektronik (nicht enthalten)
- 1× GC9A01 1.28" Rund-TFT (240×240, SPI), gerade Stiftleiste oder Litzen
- 1× ESP32-C3 Super Mini (USB-C)
- 7–8 Litzen oder Dupont-Kabel
- optional 2× Gummifüße ⌀8 mm

#### 🛠️ Montage
1. Display von hinten in die Aufnahme legen: Glas nach vorn, Kinn/FPC **nach unten** zwischen die zwei Stifte.
2. Klemmring von hinten eindrücken (Öffnung nach unten). Die Rippen am Ring halten ihn per Presspassung.
3. Verkabeln. Am Display eine **gerade Stiftleiste nach hinten** nutzen oder direkt anlöten, eine Winkel-Stiftleiste passt nicht. Stiftleisten am ESP32 sollten zur Puck-Mitte zeigen.
4. ESP32-C3 mit dem **USB-C-Ende voran** in die Schienen am Deckel schieben, bis die Haken einrasten.
5. Deckel einsetzen (Schlitz oben auf die Nase im Gehäuse) und eindrücken, bis er einrastet.
6. Optional 2 Gummifüße unter den Fuß kleben.

Zum Öffnen den Deckel an einem der Schlitze mit dem Fingernagel heraushebeln.

#### 📄 Lizenz
**Standard-Digitaldateilizenz**: nur persönliche, nicht-kommerzielle Nutzung.

---

## 5) DESCRIPTION — ENGLISH

### Round Display Puck for GC9A01 + ESP32-C3

A new variant of my [GC9A01 desk stand](https://makerworld.com/de/models/3082754-tischstander-fur-gc9a01-1-28-display-esp32-c3),
this time as a **round puck (⌀64 mm)** tilted back by 15°, standing on an integrated wedge
foot. The electronics, wiring and firmware are identical to the original, and the display
mount is copied 1:1 from the tested original.

#### ✨ Highlights
- ⭕ **Round**: the round display sits centred in a round body
- 🔩 **No screws**: press-fit clamp ring, snap-bead lid, snap rails for the ESP32 on the lid
- 🖨️ **No supports**: ~49 min on a Bambu A1, ~33 g PLA, all 3 parts on one plate
- 🔌 **USB-C at the back** with a recess for the plug
- 💻 **5 ready-made firmwares** you flash in the browser, no Arduino needed

#### 💻 Flash in your browser
**Web flasher:** https://medpex.github.io/display-case-gc9a01/ (Chrome/Edge, desktop)
- **GC9A01 HUD**: clock · weather · sun arc · date. WiFi and location are set up in the browser on first boot.
- **4 zero-setup demos:** Warp Starfield · Matrix Rain · Fire · Plasma

#### 🔧 Wiring (GC9A01 → ESP32-C3 Super Mini)
VCC→3V3 · GND→GND · SCL→GPIO4 · SDA→GPIO6 · RES→GPIO5 · DC→GPIO7 · CS→GPIO10 · BLK→3V3

#### 🧰 Required electronics (not included)
- 1× GC9A01 1.28" round TFT · 1× ESP32-C3 Super Mini · 7–8 wires · optional 2 rubber feet ⌀8 mm

#### 🛠️ Assembly
1. Insert the display from the back: glass first, chin/FPC **down** between the two pins.
2. Press the clamp ring in from the back with its opening facing down.
3. Wire it up. On the display, use a **straight header pointing backwards** or solder directly, because a right-angle header does not fit. Headers on the ESP32 should point towards the centre.
4. Slide the ESP32-C3 into the lid rails **USB-C end first** until the hooks click.
5. Line up the lid slot with the key at the top and press the lid in until it snaps.
6. Optional: add 2 rubber feet.

#### 📄 License
**Standard Digital File License**: personal, non-commercial use only.

---

## 6) DRUCKPROFIL / PRINT SETTINGS

| Setting | Value |
|---|---|
| Printer | Bambu Lab A1 (tested slice), any 0.4 mm |
| Material | PLA |
| Layer height | 0.2 mm |
| Walls | 4 |
| Infill | 15 % gyroid |
| Supports | **None** |
| Plate | `PUCK-alle-teile.3mf` (parts already oriented) |
| Filament | ~33 g |
| Time | ~49 min (Bambu Studio 2.08, A1 0.4, PLA Basic) |

---

## 7) BILD-CHECKLISTE

- [x] Cover 4:3: `docs/img/cover-4x3.png` (Rendering mit Beispiel-HUD auf dem Glas)
- [x] Cover 3:4: `docs/img/cover-3x4.png`
- [x] Galerie-Renderings: `render-front.png`, `render-side.png`, `render-rear.png`, `render-exploded.png`, `render-lid.png`, `hero-screen.png`
- [x] `docs/wiring.png`
- [ ] **Foto vom echten Druck** nach dem Testdruck (Cover später durch Foto ersetzen, das bringt auf MakerWorld mehr)
- [ ] Foto Rückseite mit eingestecktem USB-C
- [ ] Foto Original-Ständer und Puck nebeneinander

> Hinweis: Die Cover sind Renderings. Das HUD auf dem Glas ist ein gezeichneter Beispiel-Screen.
> Bis Fotos vom echten Druck da sind, in der Beschreibung als „Render“ kennzeichnen.

---

## 8) LINKS
- **Original:** https://makerworld.com/de/models/3082754-tischstander-fur-gc9a01-1-28-display-esp32-c3
- **Web-Flasher:** https://medpex.github.io/display-case-gc9a01/

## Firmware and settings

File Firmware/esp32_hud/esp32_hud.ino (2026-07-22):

/*
 * GC9A01 HUD  -  ESP32-C3 Super Mini + GC9A01 (240x240 round)
 * Rotating info display: Clock | Weather | Sun/Daylight | Date  (+ AURORA show)
 *
 * White-label build — contains NO personal data. WiFi, location and timezone are
 * configured by the end user through a captive-portal on first boot:
 *   1) Flash, then power the device.
 *   2) It opens a WiFi hotspot "GC9A01-HUD-Setup" — join it with a phone/laptop.
 *   3) Pick your WiFi and (optionally) set City / Latitude / Longitude / Timezone.
 *   4) Settings are stored in flash (NVS); the clock/weather then run via NTP + Open-Meteo.
 * To change WiFi or location later: erase flash and re-flash, or hold no button —
 * simply re-open the portal by flashing again.
 *
 * Weather: Open-Meteo (no API key). Time: NTP. No cloud account, no telemetry.
 *
 * Wiring: SCLK=4  MOSI=6  RST=5  DC=7  CS=10  VCC=3V3  GND=GND  (BLK=3V3)
 * Libraries: GFX Library for Arduino, ArduinoJson, WiFiManager (tzapu)
 * Build: arduino-cli ... --fqbn esp32:esp32:esp32c3:CDCOnBoot=cdc,PartitionScheme=huge_app
 */

#include <Arduino_GFX_Library.h>
#include <WiFi.h>
#include <WiFiClientSecure.h>
#include <HTTPClient.h>
#include <WiFiManager.h>
#include <Preferences.h>
#include <ArduinoJson.h>
#include <time.h>
#include <sys/time.h>
#include <math.h>

// loopTask stack bump (inline TLS fetch needs headroom)
SET_LOOP_TASK_STACK_SIZE(16 * 1024);

// ---------- Pins ----------
static const int8_t PIN_SCLK = 4, PIN_MOSI = 6, PIN_RST = 5, PIN_DC = 7, PIN_CS = 10;

// ---------- WiFi setup portal ----------
static const char* AP_NAME = "GC9A01-HUD-Setup";   // hotspot SSID shown on first boot
static const uint16_t PORTAL_TIMEOUT_S = 180;       // portal stays open, then falls back

// ---------- NTP ----------
static const char* NTP1 = "pool.ntp.org", *NTP2 = "time.google.com", *NTP3 = "time.nist.gov";
static const uint32_t RESYNC_MS = 3600000UL;

// ---------- Location / timezone DEFAULTS (user-overridable via portal, stored in NVS) ----------
// If you self-compile you can change these; end users set them in the setup portal.
static const char* DEF_CITY = "BERLIN";
static const char* DEF_LAT  = "52.5200";
static const char* DEF_LON  = "13.4050";
static const char* DEF_TZ   = "CET-1CEST,M3.5.0,M10.5.0/3";   // POSIX TZ (Europe/Berlin incl. DST)

// runtime config (loaded from NVS or defaults)
char cfgCity[24], cfgLat[16], cfgLon[16], cfgTz[48];
char wxUrl[352];                 // built from cfgLat/cfgLon at boot
Preferences prefs;
bool shouldSaveCfg = false;

// ---------- Weather refresh ----------
static const uint32_t WX_REFRESH_MS = 900000UL;   // 15 min
static const uint32_t WX_RETRY_MS   = 30000UL;    // error retry
static const int FORECAST_STORE = 48;             // hours kept
static const int SPARK_HOURS = 12;                // hours shown
static const size_t MIN_HEAP_FETCH = 45000;       // below this: skip fetch

// ---------- Operation ----------
static const int DAILY_REBOOT_HOUR = 4;
static const uint16_t TRANSITION_MS = 280;

// ---------- Geometry ----------
static const int16_t CX = 120, CY = 120, R = 120;
static const uint32_t SPI_HZ = 40000000UL;

// ---------- Display ----------
Arduino_DataBus *bus = new Arduino_HWSPI(PIN_DC, PIN_CS, PIN_SCLK, PIN_MOSI, GFX_NOT_DEFINED);
Arduino_GFX *panel   = new Arduino_GC9A01(bus, PIN_RST, 0, true);

// Framebuffer statically in .bss (the C3's largest contiguous heap block is too small
// for a 115 KB canvas malloc -> would crash-loop). Canvas begin() then allocates nothing.
static uint16_t FRAMEBUF[240 * 240];
class StaticCanvas : public Arduino_Canvas {
public:
  StaticCanvas(int16_t w, int16_t h, Arduino_G *output, uint16_t *buf)
      : Arduino_Canvas(w, h, output) { _framebuffer = buf; }
};
Arduino_Canvas *gfx = new StaticCanvas(240, 240, panel, FRAMEBUF);
bool gfxOk = false;

// ---------- Colors (LUMEN) ----------
uint16_t L_INK, L_WELL, L_WELL_D, L_STEEL, L_STEELD, L_HAIR, L_IVORY,
         L_AMBER, L_AMBER_M, L_ICE, L_ICE_D, L_ALERT, L_ALERT_D, L_GREEN;

// ---------- Weather model ----------
struct Weather {
  bool valid = false;
  float t = 0, tmax = 0, tmin = 0, wind = 0;
  int hum = 0, code = -1;
  char sunrise[6] = "--:--", sunset[6] = "--:--";
  int8_t hourly[FORECAST_STORE];
};
Weather wx;
uint32_t wxNext = 0;
int wxErr = 0;

// ---------- State ----------
bool timeValid = false;
uint32_t lastResync = 0, screenStart = 0, reconnectLast = 0;
uint8_t screen = 0;
bool rebootedToday = false;
uint32_t transStart = 0; bool inTransition = false;

static const char* WD[] = {"Sonntag","Montag","Dienstag","Mittwoch","Donnerstag","Freitag","Samstag"};
static const char* MO[] = {"Jan","Feb","Maerz","April","Mai","Juni","Juli","Aug","Sep","Okt","Nov","Dez"};

// ================= drawing helpers =================
static inline void polar(float deg, float len, float &x, float &y) {
  float r = deg * (float)M_PI / 180.0f;
  x = CX + sinf(r) * len; y = CY - cosf(r) * len;
}
static int textW(const char* s, uint8_t sz) { return (int)strlen(s) * 6 * sz; }
static int printAt(int x, int yTop, const char* s, uint8_t sz, uint16_t col) {
  gfx->setTextColor(col); gfx->setTextSize(sz); gfx->setCursor(x, yTop); gfx->print(s);
  return x + textW(s, sz);
}
static void centerText(int cx, int cy, const char* s, uint8_t sz, uint16_t col) {
  printAt(cx - textW(s, sz) / 2, cy - 4 * sz, s, sz, col);
}
static void degMark(int x, int yTop, uint8_t sz, uint16_t col) { gfx->drawCircle(x + 2*sz, yTop + 2*sz, sz, col); }

static inline float easeOutCubic(float t) { float f = t-1.0f; return f*f*f + 1.0f; }
static void drawIrisMask(float p) {
  int rVis = (int)(128 * easeOutCubic(p));
  for (int r = 128; r > rVis; r--) gfx->drawCircle(CX, CY, r, L_INK);
}
static void drawBase() {
  gfx->fillScreen(L_INK);
  gfx->fillCircle(CX, CY, 118, L_WELL);
  gfx->drawCircle(CX, CY, 116, L_STEELD);
}
static void eyebrow(const char* s, uint16_t col) { centerText(120, 30, s, 1, col); }
static void navPips(int active, int n) {
  int sp = 10, y = 214, x0 = CX - (n-1)*sp/2;
  for (int i = 0; i < n; i++) gfx->fillCircle(x0+i*sp, y, i==active?3:2, i==active?L_AMBER:L_STEEL);
}

// ================= time / holiday =================
static bool getNow(struct tm &ti, float &subsec) {
  struct timeval tv; gettimeofday(&tv, NULL);
  time_t t = tv.tv_sec; localtime_r(&t, &ti);
  subsec = tv.tv_usec / 1000000.0f;
  return ti.tm_year > (2020 - 1900);
}
static long daysUntil(int y, int mon, int d) {
  struct timeval tv; gettimeofday(&tv, NULL);
  time_t now = tv.tv_sec; struct tm n; localtime_r(&now, &n);
  n.tm_hour = n.tm_min = n.tm_sec = 0;
  time_t nowMid = mktime(&n);
  struct tm tgt = {0}; tgt.tm_year = y-1900; tgt.tm_mon = mon-1; tgt.tm_mday = d; tgt.tm_isdst = -1;
  return (long)round(difftime(mktime(&tgt), nowMid) / 86400.0);
}
static int hhmmToMin(const char* s) { int h,m; if (sscanf(s, "%d:%d", &h, &m) == 2) return h*60+m; return -1; }

static void easter(int y, int &mon, int &day) {
  int a=y%19,b=y/100,c=y%100,d=b/4,e=b%4,f=(b+8)/25,g=(b-f+1)/3;
  int h=(19*a+b-d-g+15)%30,i=c/4,k=c%4,l=(32+2*e+2*i-h-k)%7,m=(a+11*h+22*l)/451;
  mon=(h+l-7*m+114)/31; day=((h+l-7*m+114)%31)+1;
}
static const char* holiday(const struct tm &ti) {
  int y=ti.tm_year+1900, m=ti.tm_mon+1, d=ti.tm_mday;
  if (m==1&&d==1) return "Neujahr";
  if (m==5&&d==1) return "Tag der Arbeit";
  if (m==10&&d==3) return "Tag dt. Einheit";
  if (m==12&&d==25) return "1. Weihnacht";
  if (m==12&&d==26) return "2. Weihnacht";
  int em,ed; easter(y,em,ed); long diff = -daysUntil(y,em,ed);
  if (diff==-2) return "Karfreitag";
  if (diff==1)  return "Ostermontag";
  if (diff==39) return "Himmelfahrt";
  if (diff==50) return "Pfingstmontag";
  return nullptr;
}

// ================= weather fetch =================
static void extractHHMM(const char* iso, char out[6]) {
  const char* t = strchr(iso, 'T');
  if (t && strlen(t+1) >= 5) { memcpy(out, t+1, 5); out[5] = '\0'; }
}
static bool fetchWeather() {
  if (WiFi.status() != WL_CONNECTED) { wxErr = -1; return false; }
  if (ESP.getFreeHeap() < MIN_HEAP_FETCH) { wxErr = -4; return false; }
  WiFiClientSecure client; client.setInsecure();
  HTTPClient http; http.setConnectTimeout(6000); http.setTimeout(6000);
  if (!http.begin(client, wxUrl)) { wxErr = -2; return false; }
  int code = http.GET(); wxErr = code;
  bool ok = false;
  if (code == 200) {
    String payload = http.getString();
    JsonDocument doc;
    if (!deserializeJson(doc, payload)) {
      wx.t    = doc["current"]["temperature_2m"]     | 0.0f;
      wx.hum  = doc["current"]["relative_humidity_2m"]| 0;
      wx.code = doc["current"]["weather_code"]        | -1;
      wx.wind = doc["current"]["wind_speed_10m"]      | 0.0f;
      wx.tmax = doc["daily"]["temperature_2m_max"][0] | 0.0f;
      wx.tmin = doc["daily"]["temperature_2m_min"][0] | 0.0f;
      extractHHMM(doc["daily"]["sunrise"][0] | "", wx.sunrise);
      extractHHMM(doc["daily"]["sunset"][0]  | "", wx.sunset);
      JsonArray h = doc["hourly"]["temperature_2m"];
      for (int i = 0; i < FORECAST_STORE; i++)
        wx.hourly[i] = (i < (int)h.size()) ? (int8_t)roundf(h[i].as<float>()) : 0;
      wx.valid = true; ok = true;
    } else wxErr = -3;
  }
  http.end();
  Serial.printf("[wx] ok=%d err=%d heap=%u\n", ok, wxErr, ESP.getFreeHeap());
  return ok;
}

// ================= weather icons =================
static const char* wxLabel(int c) {
  if (c==0) return "Klar"; if (c==1) return "Heiter"; if (c==2) return "Wolkig"; if (c==3) return "Bedeckt";
  if (c==45||c==48) return "Nebel"; if (c>=51&&c<=57) return "Niesel"; if (c>=61&&c<=67) return "Regen";
  if (c>=71&&c<=77) return "Schnee"; if (c>=80&&c<=82) return "Schauer"; if (c>=85&&c<=86) return "Schneeschauer";
  if (c>=95) return "Gewitter"; return "--";
}
static void drawWxIcon(int cx, int cy, int c) {
  bool rain=(c>=51&&c<=67)||(c>=80&&c<=82)||c>=95, snow=(c>=71&&c<=77)||(c>=85&&c<=86);
  bool cloud=(c>=2&&c<=48)||rain||snow, sun=(c<=1);
  if (sun) {
    for (int a=0;a<360;a+=45){ float x1,y1,x2,y2; polar(a,11,x1,y1); polar(a,16,x2,y2);
      gfx->drawLine(cx+(x1-CX),cy+(y1-CY),cx+(x2-CX),cy+(y2-CY),L_AMBER);}
    gfx->fillCircle(cx,cy,9,L_AMBER); return;
  }
  if (c==1) gfx->fillCircle(cx+9,cy-7,6,L_AMBER);
  if (cloud){ gfx->fillCircle(cx-7,cy,7,L_IVORY); gfx->fillCircle(cx+5,cy-3,9,L_IVORY);
    gfx->fillCircle(cx+11,cy+2,6,L_IVORY); gfx->fillRect(cx-11,cy+2,24,7,L_IVORY);}
  if (rain) for (int i=-1;i<=1;i++) gfx->drawLine(cx+i*7,cy+11,cx+i*7-3,cy+18,L_ICE);
  if (snow) for (int i=-1;i<=1;i++) gfx->fillCircle(cx+i*7,cy+15,2,L_ICE);
}

// ================= screens =================
static void screenClock(const struct tm &ti, float subsec) {
  char eb[36]; snprintf(eb, sizeof(eb), "%s . %d. %s", WD[ti.tm_wday], ti.tm_mday, MO[ti.tm_mon]);
  eyebrow(eb, L_STEEL);
  char t[8]; snprintf(t, sizeof(t), "%02d:%02d", ti.tm_hour, ti.tm_min);
  centerText(120, 102, t, 6, L_IVORY);
  int bx=60, by=150, bw=120;
  gfx->fillRoundRect(bx, by, bw, 4, 2, L_HAIR);
  float sf = (ti.tm_sec + subsec) / 60.0f; int fw = (int)(sf * bw);
  if (fw > 0) gfx->fillRoundRect(bx, by, fw, 4, 2, L_ICE);
  char kw[10]; strftime(kw, sizeof(kw), "KW %V", &ti); centerText(120, 176, kw, 1, L_STEEL);
  navPips(0, 4);
}

static void screenWeather(const struct tm &ti, float subsec) {
  (void)subsec;
  eyebrow(cfgCity, L_STEEL);
  if (!wx.valid){ centerText(120,104,"WETTER LAEDT",2,L_AMBER);
    char e[20]; snprintf(e,sizeof(e),"http=%d",wxErr); centerText(120,132,e,1,L_STEEL); navPips(1,4); return; }
  char t[6]; snprintf(t,sizeof(t),"%.0f",wx.t);
  int w=textW(t,6), sx=86-w/2, yt=96-24;
  int ex=printAt(sx,yt,t,6,L_IVORY); degMark(ex,yt,3,L_IVORY);
  centerText(86,132,wxLabel(wx.code),1,L_STEEL);
  drawWxIcon(172,80,wx.code);
  int x0=44,x1=196,y0=150,y1=182,start=ti.tm_hour, lo=127,hi=-127;
  for (int i=0;i<SPARK_HOURS;i++){ int v=wx.hourly[(start+i)%FORECAST_STORE]; if(v<lo)lo=v; if(v>hi)hi=v; }
  if (hi==lo) hi=lo+1;
  int pxs[SPARK_HOURS], pys[SPARK_HOURS];
  for (int i=0;i<SPARK_HOURS;i++){ int v=wx.hourly[(start+i)%FORECAST_STORE];
    pxs[i]=x0+i*(x1-x0)/(SPARK_HOURS-1); pys[i]=y1-(v-lo)*(y1-y0)/(hi-lo); }
  for (int i=0;i<SPARK_HOURS-1;i++){ gfx->drawLine(pxs[i],pys[i]+1,pxs[i+1],pys[i+1]+1,L_ICE_D);
    gfx->drawLine(pxs[i],pys[i],pxs[i+1],pys[i+1],L_ICE); }
  gfx->fillCircle(pxs[SPARK_HOURS-1],pys[SPARK_HOURS-1],3,L_AMBER);
  char hh[6]; snprintf(hh,sizeof(hh),"%d",hi); printAt(x0,y0-8,hh,1,L_STEEL);
  char ll[6]; snprintf(ll,sizeof(ll),"%d",lo); printAt(x0,y1+3,ll,1,L_STEEL);
  navPips(1,4);
}

static void screenSun(const struct tm &ti, float subsec) {
  (void)subsec;
  eyebrow("SONNE", L_STEEL);
  gfx->fillRect(0, 150, 240, 90, L_WELL_D);
  gfx->drawFastHLine(20, 150, 200, L_STEEL);
  int prevx=40, prevy=150;
  for (int x=40; x<=200; x+=4){ float nx=(x-120)/80.0f; int yy=150-(int)((1.0f-nx*nx)*88.0f);
    gfx->drawLine(prevx,prevy+1,x,yy+1,L_AMBER_M); gfx->drawLine(prevx,prevy,x,yy,L_AMBER); prevx=x; prevy=yy; }
  int sr=hhmmToMin(wx.sunrise), ss=hhmmToMin(wx.sunset);
  if (wx.valid && sr>0 && ss>sr){
    int now=ti.tm_hour*60+ti.tm_min; float f=constrain((float)(now-sr)/(ss-sr),0.0f,1.0f);
    int sxp=40+(int)(f*160); float nx=(sxp-120)/80.0f; int syp=150-(int)((1.0f-nx*nx)*88.0f);
    bool day=(now>=sr && now<=ss); uint16_t sc=day?L_AMBER:L_STEEL;
    for (int a=0;a<360;a+=45){ float x1,y1,x2,y2; polar(a,9,x1,y1); polar(a,13,x2,y2);
      gfx->drawLine(sxp+(x1-CX),syp+(y1-CY),sxp+(x2-CX),syp+(y2-CY),sc); }
    gfx->fillCircle(sxp,syp,6,sc); gfx->fillCircle(sxp,syp,3,L_IVORY);
  }
  if (sr>0 && ss>sr){ int len=ss-sr; char dl[8]; snprintf(dl,sizeof(dl),"%d:%02d",len/60,len%60);
    centerText(120,112,dl,5,L_IVORY); }
  else centerText(120,112,"--:--",5,L_STEEL);
  centerText(120,136,"TAGESLICHT",1,L_STEEL);
  printAt(46,166,wx.sunrise,1,L_IVORY); printAt(196-textW(wx.sunset,1),166,wx.sunset,1,L_IVORY);
  centerText(52,178,"auf",1,L_STEEL); centerText(190,178,"unter",1,L_STEEL);
  navPips(2,4);
}

static void screenDate(const struct tm &ti, float subsec) {
  (void)subsec;
  eyebrow("HEUTE", L_STEEL);
  const char* hn = holiday(ti);
  if (hn) centerText(120,50,hn,1,L_AMBER);
  centerText(120,72,WD[ti.tm_wday],2,L_IVORY);
  char dd[4]; snprintf(dd,sizeof(dd),"%d",ti.tm_mday); centerText(120,118,dd,7,L_IVORY);
  char my[16]; snprintf(my,sizeof(my),"%s %d",MO[ti.tm_mon],ti.tm_year+1900); centerText(120,162,my,1,L_STEEL);
  char kwb[4]; strftime(kwb,sizeof(kwb),"%V",&ti); int kw=atoi(kwb);
  int x0=44,x1=196,y=184;
  for (int w=1; w<=52; w++){ int x=x0+(w-1)*(x1-x0)/51; bool on=(w==kw);
    gfx->drawFastVLine(x, on?y-5:y-2, on?7:4, on?L_AMBER:L_STEEL); }
  char kl[10]; snprintf(kl,sizeof(kl),"KW %d",kw); centerText(120,200,kl,1,L_STEEL);
  navPips(3,4);
}

// ================= AURORA — random show (>=1x/h, 50 s) =================
static const uint32_t AURORA_MS = 50000UL;
static bool     aurActive = false;
static uint32_t aurStart  = 0;
static int      aurHour   = -1, aurAtSec = 0;
static bool     aurFired  = false, aurInit = false;
static uint32_t aurSeed   = 0x1234ABCDu;
static float frnd() { aurSeed = aurSeed*1664525u + 1013904223u; return (float)((aurSeed>>9)&0xFFFF)/65535.0f; }

static const int STAR_N = 120;
static float starX[STAR_N], starY[STAR_N], starZ[STAR_N];
static void auroraEnter() { aurActive = true; aurStart = millis(); aurInit = false; aurSeed ^= millis()*2654435761u; }
static void starInit() { for (int i=0;i<STAR_N;i++){ starX[i]=frnd()*2-1; starY[i]=frnd()*2-1; starZ[i]=frnd()*0.9f+0.1f; } aurInit=true; }

static void fxStarfield(float t) {
  (void)t; gfx->fillScreen(L_INK);
  const float K = 92.0f;
  for (int i=0;i<STAR_N;i++){
    starZ[i]-=0.013f; if (starZ[i]<=0.05f){ starX[i]=frnd()*2-1; starY[i]=frnd()*2-1; starZ[i]=1.0f; }
    float sx=CX+starX[i]/starZ[i]*K, sy=CY+starY[i]/starZ[i]*K;
    float pz=starZ[i]+0.06f, pxp=CX+starX[i]/pz*K, pyp=CY+starY[i]/pz*K;
    float b=1.0f-starZ[i];
    uint16_t col = b>0.78f ? L_IVORY : b>0.42f ? L_ICE : L_ICE_D;
    gfx->drawLine(pxp,pyp,sx,sy,col);
    if (b>0.86f) gfx->fillCircle(sx,sy,1,L_AMBER);
  }
}
static void fxPlasma(float t) {
  const int bs=8;
  for (int y=0;y<240;y+=bs) for (int x=0;x<240;x+=bs){
    int dx=x+bs/2-CX, dy=y+bs/2-CY; if (dx*dx+dy*dy>118*118) continue;
    float d=sqrtf((float)(dx*dx+dy*dy));
    float v=sinf(x*0.045f+t)+sinf(y*0.05f-t*1.1f)+sinf((x+y)*0.03f+t*0.7f)+sinf(d*0.06f-t*1.6f);
    v=(v+4.0f)/8.0f;
    uint16_t col = v<0.35f?L_INK : v<0.55f?L_ICE_D : v<0.72f?L_ICE : v<0.88f?L_AMBER_M : L_AMBER;
    gfx->fillRect(x,y,bs,bs,col);
  }
}
static void fxLissajous(float t) {
  gfx->fillScreen(L_INK);
  const float A=94.0f, a=3.0f, b=2.0f, ph=t*0.6f, rot=t*0.32f; const int M=95;
  for (int i=0;i<M;i++){
    float p=t*2.2f - i*0.055f;
    float x=A*sinf(a*p+ph), y=A*sinf(b*p);
    float rx=x*cosf(rot)-y*sinf(rot), ry=x*sinf(rot)+y*cosf(rot);
    int sx=CX+(int)rx, sy=CY+(int)ry; float f=1.0f-(float)i/M;
    if (f>0.6f){ gfx->drawCircle(sx,sy,3,L_AMBER_M); gfx->fillCircle(sx,sy,2,L_AMBER); }
    else if (f>0.3f) gfx->fillCircle(sx,sy,1,L_ICE);
    else gfx->drawPixel(sx,sy,L_ICE_D);
  }
}
static void screenAurora() {
  if (!aurInit) starInit();
  uint32_t e=millis()-aurStart; float t=e/1000.0f;
  int phase=(e/16000UL)%3;
  if (phase==0) fxStarfield(t); else if (phase==1) fxPlasma(t); else fxLissajous(t);
  if (e<2600) centerText(120,120,"AURORA",3,L_IVORY);
  gfx->drawCircle(CX,CY,118,L_STEELD);
}

// ---------- screen registry ----------
struct ScreenDef { void (*draw)(const struct tm&, float); uint32_t dwell; void (*onEnter)(); };
static const uint32_t DWELL_CLOCK_MS = 180000UL;  // clock: 3 min
static const uint32_t DWELL_OTHER_MS = 60000UL;   // others: 1 min
static const ScreenDef SCREENS[] = {
  { screenClock,   DWELL_CLOCK_MS, nullptr },
  { screenWeather, DWELL_OTHER_MS, nullptr },
  { screenSun,     DWELL_OTHER_MS, nullptr },
  { screenDate,    DWELL_OTHER_MS, nullptr },
};
static const uint8_t SCREEN_COUNT = sizeof(SCREENS)/sizeof(SCREENS[0]);

// ================= config (NVS) + WiFi portal =================
static void loadConfig() {
  prefs.begin("hud", true);
  strlcpy(cfgCity, prefs.getString("city", DEF_CITY).c_str(), sizeof(cfgCity));
  strlcpy(cfgLat,  prefs.getString("lat",  DEF_LAT ).c_str(), sizeof(cfgLat));
  strlcpy(cfgLon,  prefs.getString("lon",  DEF_LON ).c_str(), sizeof(cfgLon));
  strlcpy(cfgTz,   prefs.getString("tz",   DEF_TZ  ).c_str(), sizeof(cfgTz));
  prefs.end();
}
static void saveConfig() {
  prefs.begin("hud", false);
  prefs.putString("city", cfgCity); prefs.putString("lat", cfgLat);
  prefs.putString("lon", cfgLon);   prefs.putString("tz",  cfgTz);
  prefs.end();
}
static void buildWxUrl() {
  snprintf(wxUrl, sizeof(wxUrl),
    "https://api.open-meteo.com/v1/forecast?latitude=%s&longitude=%s"
    "&current=temperature_2m,relative_humidity_2m,weather_code,wind_speed_10m"
    "&hourly=temperature_2m"
    "&daily=temperature_2m_max,temperature_2m_min,sunrise,sunset"
    "&timezone=auto&forecast_days=2", cfgLat, cfgLon);
}
static void onSaveCfg() { shouldSaveCfg = true; }

// Show a static message screen (used before/while the WiFi portal is open).
static void showSetupMsg(const char* l1, const char* l2, const char* l3) {
  if (!gfxOk) return;
  drawBase();
  if (l1) centerText(120, 92,  l1, 2, L_AMBER);
  if (l2) centerText(120, 124, l2, 1, L_IVORY);
  if (l3) centerText(120, 144, l3, 1, L_ICE);
  gfx->flush();
}
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
void loop() {
  uint32_t frameStart = millis();
  bool online = (WiFi.status() == WL_CONNECTED);

  if (!gfxOk) { delay(1000); return; }

  // light auto-reconnect if the link dropped (creds are stored by WiFiManager)
  if (!online && millis()-reconnectLast > 15000) { reconnectLast = millis(); WiFi.reconnect(); }

  if (online && millis()-lastResync > RESYNC_MS) { configTzTime(cfgTz, NTP1, NTP2, NTP3); lastResync=millis(); }
  if (online && millis() >= wxNext) { bool ok = fetchWeather(); wxNext = millis() + (ok ? WX_REFRESH_MS : WX_RETRY_MS); }

  struct tm ti; float subsec; timeValid = getNow(ti, subsec);
  if (timeValid){
    if (ti.tm_hour==DAILY_REBOOT_HOUR && !rebootedToday){ rebootedToday=true; ESP.restart(); }
    if (ti.tm_hour!=DAILY_REBOOT_HOUR) rebootedToday=false;
    if (ti.tm_hour != aurHour){ aurHour=ti.tm_hour; aurFired=false; aurAtSec=(int)(frnd()*(3600-60)); }
    int secOfHour = ti.tm_min*60 + ti.tm_sec;
    if (!aurFired && !aurActive && secOfHour>=aurAtSec){ aurFired=true; auroraEnter(); }
  }
  if (aurActive && millis()-aurStart >= AURORA_MS) aurActive=false;

  if (aurActive) { screenAurora(); gfx->flush(); uint32_t elA=millis()-frameStart; if (elA<30) delay(30-elA); return; }

  drawBase();

  if (!timeValid){
    centerText(120,98,"SYNC",3,L_IVORY);
    float a=(millis()%1500)/1500.0f*360.0f, sx,sy; polar(a,58,sx,sy); gfx->fillCircle(sx,sy,4,L_AMBER);
    centerText(120,150,online?"WLAN OK - warte NTP":"kein WLAN",1,online?L_ICE:L_AMBER);
  } else {
    if (millis()-screenStart > SCREENS[screen].dwell){
      screen=(screen+1)%SCREEN_COUNT; screenStart=millis();
      transStart=millis(); inTransition=true;
      if (SCREENS[screen].onEnter) SCREENS[screen].onEnter();
    }
    SCREENS[screen].draw(ti, subsec);
    if (inTransition){
      float p=(float)(millis()-transStart)/TRANSITION_MS;
      if (p>=1.0f) inTransition=false; else drawIrisMask(p);
    }
  }

  gfx->flush();
  uint32_t el = millis()-frameStart;
  if (el < 30) delay(30-el);
}

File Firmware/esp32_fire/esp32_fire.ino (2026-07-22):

/*
 * FIRE  -  ESP32-C3 Super Mini + GC9A01 (240x240 round)
 * Classic demoscene fire propagation (a la PSX Doom), 80x80 cell grid
 * rendered at 3x3 px. Flicker-free (full-frame canvas). No WiFi needed.
 *
 * Wiring: SCK=4  MOSI=6  RST=5  DC=7  CS=10  VCC=3V3  GND=GND  (BLK=3V3)
 * Flash: arduino-cli compile --upload -p <port> \
 *   --fqbn "esp32:esp32:esp32c3:CDCOnBoot=cdc,FlashSize=4M" esp32_fire
 */
#include <Adafruit_GFX.h>
#include <Adafruit_GC9A01A.h>
#include <SPI.h>

#define TFT_SCK 4
#define TFT_MOSI 6
#define TFT_RST 5
#define TFT_DC  7
#define TFT_CS  10

#define CELL 3                    // px per fire cell
#define FW (240 / CELL)           // 80 cells wide
#define FH (240 / CELL)           // 80 cells high
#define N_PAL 37                  // classic 37-step fire palette
#define WIND 1                    // 0 = straight up, 1 = slight drift

Adafruit_GC9A01A tft(TFT_CS, TFT_DC, TFT_RST);
GFXcanvas16 cv(240, 240);

uint8_t fire[FW * FH];            // palette index per cell
uint16_t pal[N_PAL];
uint32_t seed = 0xF12EF12E;

static uint32_t rnd() { seed ^= seed << 13; seed ^= seed >> 17; seed ^= seed << 5; return seed; }

// classic black -> red -> orange -> yellow -> white ramp
static void buildPalette() {
  static const uint8_t RGB[N_PAL][3] = {
    {7,7,7},{31,7,7},{47,15,7},{71,15,7},{87,23,7},{103,31,7},{119,31,7},{143,39,7},
    {159,47,7},{175,63,7},{191,71,7},{199,71,7},{223,79,7},{223,87,7},{223,87,7},{215,95,7},
    {215,95,7},{215,103,15},{207,111,15},{207,119,15},{207,127,15},{207,135,23},{199,135,23},{199,143,23},
    {199,151,31},{191,159,31},{191,159,31},{191,167,39},{191,167,39},{191,175,47},{183,175,47},{183,183,47},
    {183,183,55},{207,207,111},{223,223,159},{239,239,199},{255,255,255}
  };
  for (int i = 0; i < N_PAL; i++)
    pal[i] = ((RGB[i][0] & 0xF8) << 8) | ((RGB[i][1] & 0xFC) << 3) | (RGB[i][2] >> 3);
}

static inline void spreadFire(int src) {
  int r = rnd() & 3;                          // 0..3
  int dst = src - r + WIND;                   // sideways drift
  if (dst < FW) return;                       // stay inside (skip top row wrap)
  int v = fire[src] - (r & 1);                // cool down by 0 or 1
  fire[dst - FW] = (v < 0) ? 0 : v;
}

void setup() {
  SPI.begin(TFT_SCK, -1, TFT_MOSI, -1);
  tft.begin(); tft.setRotation(0); tft.fillScreen(0x0000);
  buildPalette();
  memset(fire, 0, sizeof(fire));
  for (int x = 0; x < FW; x++) fire[(FH - 1) * FW + x] = N_PAL - 1;   // bottom row = fuel
}

void loop() {
  cv.fillScreen(0x0000);
  // propagate (bottom row stays hot)
  for (int x = 0; x < FW; x++)
    for (int y = 1; y < FH; y++)
      spreadFire(y * FW + x);

  // render round-masked
  for (int y = 0; y < FH; y++) {
    for (int x = 0; x < FW; x++) {
      int px = x * CELL + CELL / 2 - 120, py = y * CELL + CELL / 2 - 120;
      if (px * px + py * py > 120 * 120) continue;      // outside round panel
      uint8_t v = fire[y * FW + x];
      if (v == 0) continue;                              // canvas already black
      cv.fillRect(x * CELL, y * CELL, CELL, CELL, pal[v]);
    }
  }
  tft.drawRGBBitmap(0, 0, cv.getBuffer(), 240, 240);
}

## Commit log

2026-07-22 Display-Case GC9A01: STLs, CAD, firmware, web flasher, docs
    - Firmware: Mega Clock (WiFiManager+NTP, offline fallback) + Warp Starfield
    - Web flasher (ESP Web Tools) under docs/ for GitHub Pages
    - Wiring diagram (SVG+PNG)
    - README (EN), BOM, CC BY 4.0 license
    [CASE-FINAL-alle-teile.3mf, CASE-FINAL.step, FINAL-Case.stl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]
2026-07-22 White-label HUD firmware; drop personal clock
    - Add Firmware/esp32_hud: rotating HUD (clock/weather/sun/date + AURORA show)
    generified from private firmware — NO secrets. WiFi + location/timezone via
    WiFiManager captive portal, persisted in NVS. Weather via Open-Meteo (no key).
    - Removed: vacation screen, Home Assistant/solar screen (+ token), OTA, hardcoded WiFi.
    - Drop superseded simple analog clock (HUD replaces it).
    - Web flasher + README + MakerWorld desc updated to HUD + Starfield.
    [esp32_hud.ino]
2026-07-22 Add Matrix Rain, Fire and Plasma demos; pin esp-web-tools to 10.4.0
    - Three new standalone demos (no WiFi): esp32_matrix, esp32_fire, esp32_plasma —
    same Adafruit GFX canvas pattern as the starfield.
    - Web flasher: cards + manifests + bins for all demos; CDN version pinned.
    - Starfield comments translated to English for repo consistency.
    - README + MakerWorld description updated to five firmwares.
2026-07-22 Switch license to MakerWorld Standard Digital File License (was CC BY 4.0)
    Match the GitHub repo's stated license to the published MakerWorld listing:
    personal/non-commercial, no redistribution/remix without permission.
2026-09-26 Add round puck housing variant (puck/)
    - puck/: ⌀64 mm round desk puck, 15° tilt, integrated wedge foot
    - same GC9A01 + ESP32-C3 electronics, wiring and firmware
    - lid v2: rigid ESP32 snap sled, 3 hold-down posts for the clamp ring,
    snug lip with crush ribs (fixes from the first test print)
    - parametric Fusion source (fusion/build_puck.py) + render/check/layout scripts
    - STL/3MF/STEP in print orientation, Bambu Studio A1 project (~60 min, ~36 g)
    - photos of the printed puck, covers, BOM, MakerWorld listing kit
    - root README: housing variants section
    [Display-Puck-GC9A01.f3d, PUCK-BambuStudio-A1.3mf, PUCK-Deckel-v2-BambuStudio-A1.3mf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]
